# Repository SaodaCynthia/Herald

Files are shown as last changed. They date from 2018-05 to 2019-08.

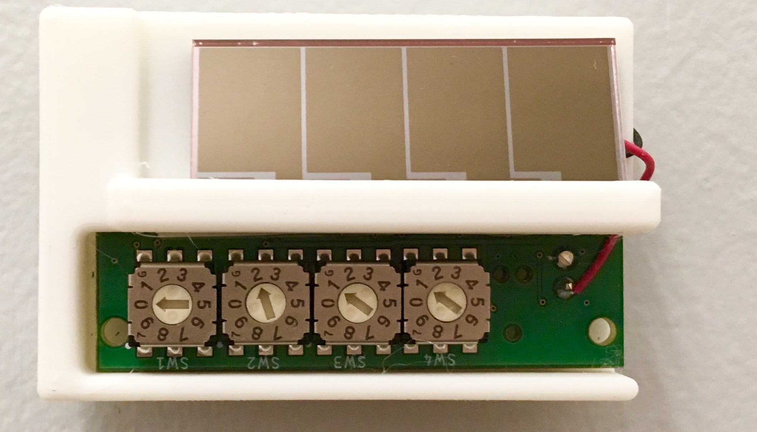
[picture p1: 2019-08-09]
media/herald.jpg

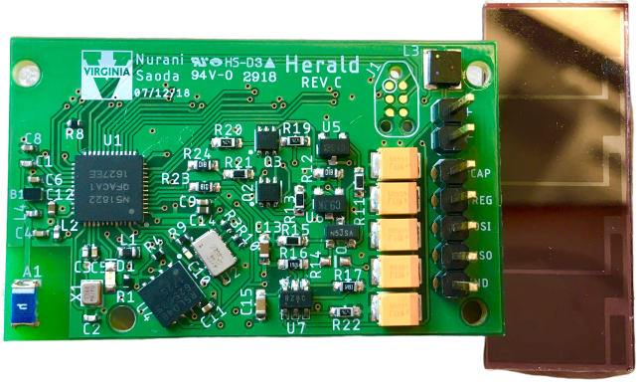
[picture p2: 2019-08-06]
media/prototype.png

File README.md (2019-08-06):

# Herald

Herald is a solar energy harvesting room number transmitter BLE beacon. It has been tested and deployed in 3 different indoor settings: a lab space with sunlight , indoor office with only indoor lights and an industrial steam plant with indoor lights. This project shows that solar energy harvesting beacons has promising future in indoor settings and performance can be further improved with planned deployment of beacons and a minimum indoor light intensity level.

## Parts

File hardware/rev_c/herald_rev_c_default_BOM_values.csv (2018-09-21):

Qty | Value | Device | Parts | Library | Description | DIGIKEY | MANUFACTURER | MOUSER | MPN | NEWARK | PROD_ID | RICHARDSON_RFPD | VALUE
5 | 100uF | 1210_CAP_POLARIZED | C16, C17, C18, C19, C20 | Gecko |  | ?478-3130-1-ND? |  |  | ?TCJB107M006R0070?
1 | BAL-NRF01D3 | BAL-NRF01D3 | B1 | chips | 50 ohm nominal input / conjugate match balun to nRF51422-QFAA, | 497-13637-1-ND | STMicroelectronics | 511-BAL-NRF01D3 | BAL-NRF01D3
1 | 10uF | CAP | C13 | Gecko |  | 445-6853-1-ND |  |  | C1608X5R1A106M080AC?
1 | 4.7uF | CAP | C15 | Gecko |  | 1276-2087-1-ND |  |  | CL10B475KQ8NQNC
2 | 0.1uF | CAPACITOR0402_CAP | C9, C11 | passives | SMD Capacitor | 399-7332-1-ND? |  |  | C0402C104M4VACTU?
1 | 1.5pF | CAPACITOR0402_CAP | C1 | passives | SMD Capacitor | 399-1002-1-ND? |  |  | ?C0402C159C5GACTU?
1 | 10nF | CAPACITOR0402_CAP | C10 | passives | SMD Capacitor | ?720-1362-1-ND |  |  | VJ0402Y103KXXAC?
2 | 12pF | CAPACITOR0402_CAP | C2, C3 | passives | SMD Capacitor | ?399-1013-1-ND? |  |  | C0402C120J5GACTU?
2 | 1nF | CAPACITOR0402_CAP | C4, C5 | passives | SMD Capacitor | ?311-1036-1-ND? |  |  | CC0402KRX7R9BB102?
1 | 1uF | CAPACITOR0402_CAP | C12 | passives | SMD Capacitor | 445-13185-1-ND |  |  | CGB2A1X5R1E105K033BC
1 | 2.2nF | CAPACITOR0402_CAP | C6 | passives | SMD Capacitor | ?490-5419-1-ND? |  |  | ?GRM155R71E222KA01D?
1 | 4.7uF | CAPACITOR0402_CAP | C14 | passives | SMD Capacitor | 445-5947-1-ND? |  |  | ?C1005X5R0J475K050BC?
1 | 47nF | CAPACITOR0402_CAP | C8 | passives | SMD Capacitor | ?445-1264-1-ND? |  |  | ?C1005X7R1C473K050BC?
1 |  | CONN_02 | J2 | SparkFun-Retired | Multi connection point. Often used as Generic Header-pin footprint for 0.1 inch spaced/style header connections | 732-5315-ND |  |  | 61300211121
1 | FM25LBTDFN-8 | FM25LBTDFN-8 | U4 | chips | IC FRAM 4KBIT 10MHZ 8SOIC | FM25L04B-DGRA-ND |  | 877-FM25L04B-DG | FM25L04B-DG?
1 | FRACTUS-2.4GHZ-FR05-S1-N-0-110 | FRACTUS-2.4GHZ-FR05-S1-N-0-110 | A1 | chips | Fractus Micro Reach Xtend |  |  |  | FR05-S1-N-0-110BULK |  |  | FR05-S1-N-0110B
1 | 15nH | INDUCTOR0402 | L2 | passives | A very specific inductor | 587-1521-1-ND |  |  | HK100515NJ-T?
1 | 6.8nH | INDUCTOR0402 | L4 | passives | A very specific inductor | 587-1515-1-ND |  |  | ?HK10056N8J-T?
1 | 10uH | INDUCTOR0603 | L1 | passives | A very specific inductor | 490-4025-1-ND |  |  | CK1608100M-T?
1 | 4.7uH | L-US | L3 | Gecko |  |  |  | 994-EPL3012-472MLB | EPL3012-472MLB
1 | BLUE | LED-BLUE0603 | D1 | SparkFun-LED | Blue SMD LED | 160-1837-1-ND |  |  | LTST-C194TBKT |  | DIO-08575 |  | BLUE
1 | MCP1640T | MCP1640 | U7 | Gecko |  | MCP1640T-I/CHYDKR-ND? |  |  | MCP1640T-I/CHY?
1 | MN1382S 2.0V | MN1382S | U5 | umich |  |  |  |  | TC54VC2102ECB713
1 | TC54VC 2.9V | MN1382S | U6 | umich |  | ?TC54VC2902ECB71DKR-ND? |  |  | TC54VC2902ECB713?
1 | NRF51822QF | NRF51822QF | U1 | chips | Multiprotocol Bluetooth® 4.0 low energy/2.4 GHz RF SoC | 1490-1042-1-ND | Nordic Semi | 949-NRF51822-QFAC-R7 | NRF51822-QFAC-R7
1 |  | PINHD-1X5 | JP1 | pinhead | PIN HEADER | 732-5318-ND |  |  | 61300511121
1 |  | PMOSSOT23 | Q1 | berkeley-epic | MOS FET |  |  |  | SI2305CDS-T1-GE3 | 55R1909
4 | 100K | RESISTOR | R11, R13, R15, R21 | Gecko |  | ?P100KHCT-ND? |  |  | ?ERJ-3EKF1003V?
1 | 100K (DNP) | RESISTOR | R14 | Gecko |  | ?P100KHCT-ND? |  |  | ?ERJ-3EKF1003V?
3 | 1K | RESISTOR | R12, R23, R24 | Gecko |  | ?A106049CT-ND? |  |  | ?CRG0603F1K0?
3 | 470K | RESISTOR | R19, R20, R22 | Gecko |  | ?1276-4902-1-ND? |  |  | ?RC1608F474CS?
1 | 649K | RESISTOR | R17 | Gecko |  | 541-649KHCT-ND? |  |  | ?CRCW0603649KFKEA?
1 | 976K | RESISTOR | R16 | Gecko |  | 541-976KHCT-ND |  |  | CRCW0603976KFKEA
2 | 10k | RESISTOR0402_RES | R3, R9 | passives | Resistor | RHM10KCECT-ND |  |  | ?ERJ-2GEJ103X?
1 | 12k | RESISTOR0402_RES | R8 | passives | Resistor | RHM12.0KCDCT-ND |  |  | ?RC0402FR-0712KL?
2 | 4.7k | RESISTOR0402_RES | R4, R10 | passives | Resistor | RHM4.7KCECT-ND |  |  | ?ERJ-2GEJ472X?
1 | 470 | RESISTOR0402_RES | R1 | passives | Resistor | RHM470CECT-ND |  |  | ERA-2AED471X
1 | RV-3049-C3 | RV-3049-C3 | U2 | chips | The RV-3049-C3 is an ultra miniature Real-Time-Clock Module |  |  |  | RV-3049-C3-32.768kHz-OPTION-A-TA-QC | RV-3049-C3
4 | SH7010TA | SH7010TA | SW1, SW2, SW3, SW4 | sh7010TA |  | 563-1207-2-ND |  |  | ?SH-7010TA?
1 | TC2030-JLINK-NL | TC2030-JLINK-NL | J1 | connector |  |  |  |  | TC2030-MCP-NL
1 | 16MHz | TXC-8Y | X1 | crystals | 2mmx1.6mm SMD Crystal | 887-2003-1-ND |  |  | ?8Y-16.000MAAV-T?
2 | US6M11TR | US6M11TR | Q2, Q3 | DUALMOS |  | US6M11CT-ND |  |  | ?US6M11TR?
1 |  | Solar Cell |  |  |  | 869-1000-ND |  |  | AM-1417CA

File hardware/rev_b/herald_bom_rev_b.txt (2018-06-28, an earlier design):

Partlist exported from C:/Users/ns8nf/Documents/eagle/sensorfinal/sensor/sensor/herald_rev_b.sch at 6/7/2018 6:50 PM

Part Value                          Device                         Package                         Description                                                    DIGIKEY          MANUFACTURER       MOUSER               MPN               NEWARK     PROD_ID   RICHARDSON_RFPD VALUE
A1   FRACTUS-2.4GHZ-FR05-S1-N-0-110 FRACTUS-2.4GHZ-FR05-S1-N-0-110 FRACTUS-ANTENNA-FR05-S1-N-0-110 Fractus Micro Reach Xtend                                                                                                                                      FR05-S1-N-0110B      
B1   BAL-NRF01D3                    BAL-NRF01D3                    BAL-NRF01D3                     50 ohm nominal input / conjugate match balun to nRF51422-QFAA, 497-13637-1-ND   STMicroelectronics 511-BAL-NRF01D3      BAL-NRF01D3                                                 
C1   1.5pF                          CAPACITOR0402_CAP              0402_CAP                        SMD Capacitor                                                                                                                                                                       
C2   12pF                           CAPACITOR0402_CAP              0402_CAP                        SMD Capacitor                                                                                                                                                                       
C3   12pF                           CAPACITOR0402_CAP              0402_CAP                        SMD Capacitor                                                                                                                                                                       
C4   1nF                            CAPACITOR0402_CAP              0402_CAP                        SMD Capacitor                                                                                                                                                                       
C5   1nF                            CAPACITOR0402_CAP              0402_CAP                        SMD Capacitor                                                                                                                                                                       
C6   2.2nF                          CAPACITOR0402_CAP              0402_CAP                        SMD Capacitor                                                                                                                                                                       
C8   47nF                           CAPACITOR0402_CAP              0402_CAP                        SMD Capacitor                                                                                                                                                                       
C9   0.1uF                          CAPACITOR0402_CAP              0402_CAP                        SMD Capacitor                                                                                                                                                                       
C10  10nF                           CAPACITOR0402_CAP              0402_CAP                        SMD Capacitor                                                                                                                                                                       
C11  0.1uF                          CAPACITOR0402_CAP              0402_CAP                        SMD Capacitor                                                                                                                                                                       
C12  1uF                            CAPACITOR0402_CAP              0402_CAP                        SMD Capacitor                                                                                                                                                                       
C13  10uF                           CAP                            R0603B                                                                                                                                                                                                              
C14  4.7uF                          CAPACITOR0402_CAP              0402_CAP                        SMD Capacitor                                                                                                                                                                       
C15  4.7uF                          CAP                            R0603B                                                                                                                                                                                                              
C16  100uF                          1210_CAP_POLARIZED             CAP1210                                                                                                                                                                                                             
C17  100uF                          1210_CAP_POLARIZED             CAP1210                                                                                                                                                                                                             
C18  100uF                          1210_CAP_POLARIZED             CAP1210                                                                                                                                                                                                             
C19  100uF                          1210_CAP_POLARIZED             CAP1210                                                                                                                                                                                                             
C20  100uF                          1210_CAP_POLARIZED             CAP1210                                                                                                                                                                                                             
D1   BLUE                           LED-BLUE0603                   LED-0603                        Blue SMD LED                                                                                                                                         DIO-08575                 BLUE 
J1   TC2030-JLINK-NL                TC2030-JLINK-NL                TC2030-IDC-NL                                                                                                                                                                                                       
JP1                                 PINHD-1X6                      1X06                            PIN HEADER                                                                                                                                                                          
JP2                                 PINHD-1X2                      1X02                            PIN HEADER                                                                                                                                                                          
L1   10uH                           INDUCTOR0603                   0603_CAP                        A very specific inductor                                       490-4025-1-ND                                                                                                        
L2   15nH                           INDUCTOR0402                   0402_CAP                        A very specific inductor                                       587-1521-1-ND                                                                                                        
L3   4.7uH                          L-US                           L2828                                                                                                                                                                                                               
L4   6.8nH                          INDUCTOR0402                   0402_CAP                        A very specific inductor                                       587-1521-1-ND                                                                                                        
Q1                                  PMOSSOT23                      SOT-23                          MOS FET                                                                                                                                                                             
Q2   US6M11TR                       US6M11TR                       TUMT6                                                                                          US6M11CT-ND                                                                                                          
Q3   US6M11TR                       US6M11TR                       TUMT6                                                                                          US6M11CT-ND                                                                                                          
R1   470                            RESISTOR0402_RES               0402_RES                        Resistor                                                       RHM470CECT-ND                                                                                                        
R3   10k                            RESISTOR0402_RES               0402_RES                        Resistor                                                       RHM10KCECT-ND                                                                                                        
R4   4.7k                           RESISTOR0402_RES               0402_RES                        Resistor                                                       RHM4.7KCECT-ND                                                                                                       
R8   12k                            RESISTOR0402_RES               0402_RES                        Resistor                                                       RHM12.0KCDCT-ND                                                                                                      
R9   10k                            RESISTOR0402_RES               0402_RES                        Resistor                                                       RHM10KCECT-ND                                                                                                        
R10  4.7k                           RESISTOR0402_RES               0402_RES                        Resistor                                                       RHM4.7KCECT-ND                                                                                                       
R11  100K                           RESISTOR                       R0603B                                                                                                                                                                                                              
R12  1K                             RESISTOR                       R0603B                                                                                                                                                                                                              
R13  100K                           RESISTOR                       R0603B                                                                                                                                                                                                              
R14  100K (DNP)                     RESISTOR                       R0603B                                                                                                                                                                                                              
R15  100K                           RESISTOR                       R0603B                                                                                                                                                                                                              
R16  976K                           RESISTOR                       R0603B                                                                                                                                                                                                              
R17  649K                           RESISTOR                       R0603B                                                                                                                                                                                                              
R19  470K                           RESISTOR                       R0603B                                                                                                                                                                                                              
R20  470K                           RESISTOR                       R0603B                                                                                                                                                                                                              
R21  100K                           RESISTOR                       R0603B                                                                                                                                                                                                              
R22  470K                           RESISTOR                       R0603B                                                                                                                                                                                                              
R23  1K                             RESISTOR                       R0603B                                                                                                                                                                                                              
R24  1K                             RESISTOR                       R0603B                                                                                                                                                                                                              
SW1  SH7010TA                       SH7010TA                       SWTICH-6                                                                                       563-1207-2-ND                                                                                                        
SW2  SH7010TA                       SH7010TA                       SWTICH-6                                                                                       563-1207-2-ND                                                                                                        
SW3  SH7010TA                       SH7010TA                       SWTICH-6                                                                                       563-1207-2-ND                                                                                                        
SW4  SH7010TA                       SH7010TA                       SWTICH-6                                                                                       563-1207-2-ND                                                                                                        
U1   NRF51822QF                     NRF51822QF                     QFN-48-6MM                      Multiprotocol Bluetooth® 4.0 low energy/2.4 GHz RF SoC         1490-1042-1-ND   Nordic Semi        949-NRF51822-QFAC-R7 NRF51822-QFAC-R7                                            
U2   RV-3049-C3                     RV-3049-C3                     MICRO-CRYSTAL-C3                The RV-3049-C3 is an ultra miniature Real-Time-Clock Module                                                                               RV-3049-C3                                
U4   FM25LBTDFN-8                   FM25LBTDFN-8                   TDFN-8@1                        IC FRAM 4KBIT 10MHZ 8SOIC                                      FM25L04B-DGRA-ND                     877-FM25L04B-DG                                                                 
U5   MN1382S 2.0V                   MN1382S                        MINI-3DC                                                                                                                                                                                                            
U6   TC54VC 2.9V                    MN1382S                        MINI-3DC                                                                                                                                                                                                            
U7   MCP1640T                       MCP1640                        SOT-23-6                                                                                                                                                                                                            
X1   16MHz                          TXC-8Y                         TXC-8Y                          2mmx1.6mm SMD Crystal                                          887-2003-1-ND

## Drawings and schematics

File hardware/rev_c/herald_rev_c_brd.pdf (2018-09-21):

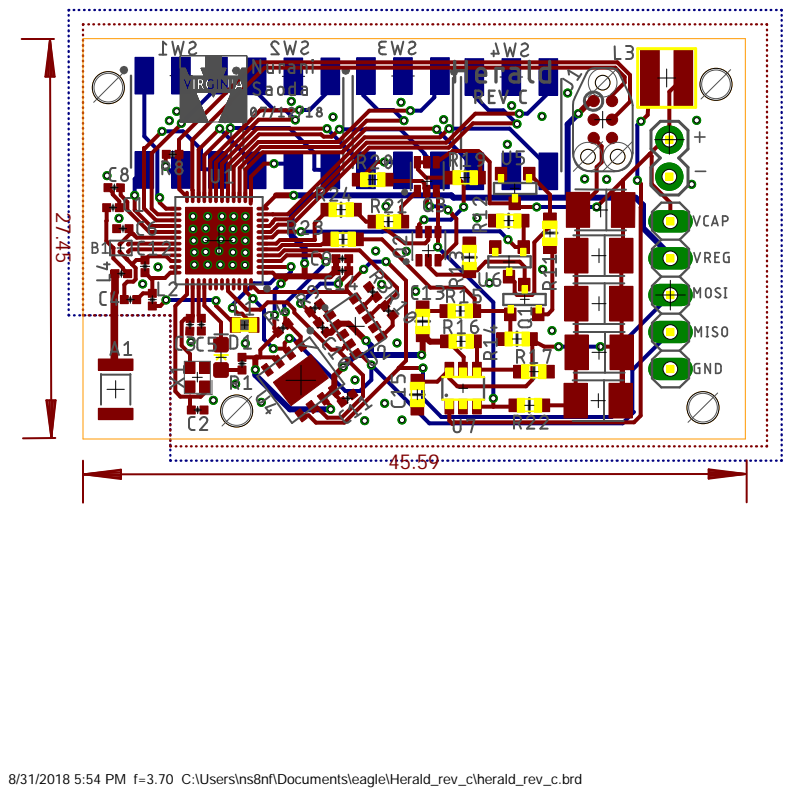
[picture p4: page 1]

8/31/2018 5:54 PM f=3.70 C:\Users\ns8nf\Documents\eagle\Herald_rev_c\herald_rev_c.brd

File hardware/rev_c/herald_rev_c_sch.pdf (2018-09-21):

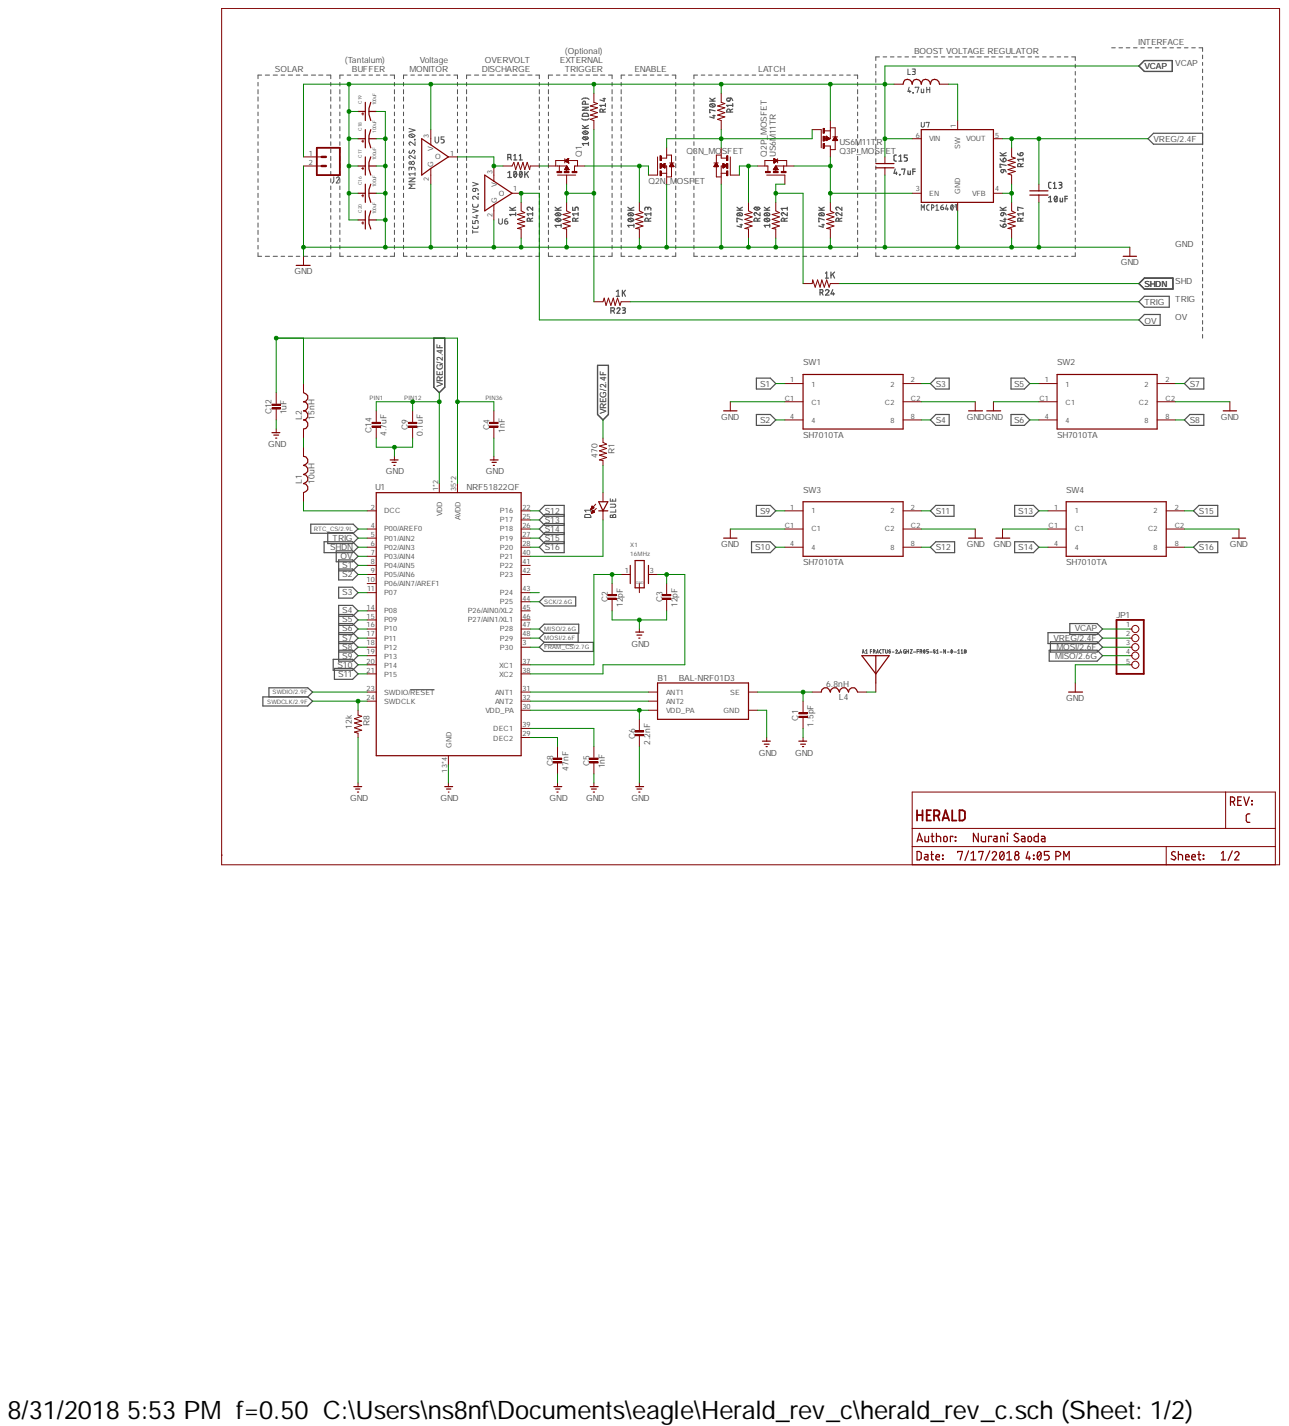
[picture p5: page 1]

8/31/2018 5:53 PM f=0.50 C:\Users\ns8nf\Documents\eagle\Herald_rev_c\herald_rev_c.sch (Sheet: 1/2)

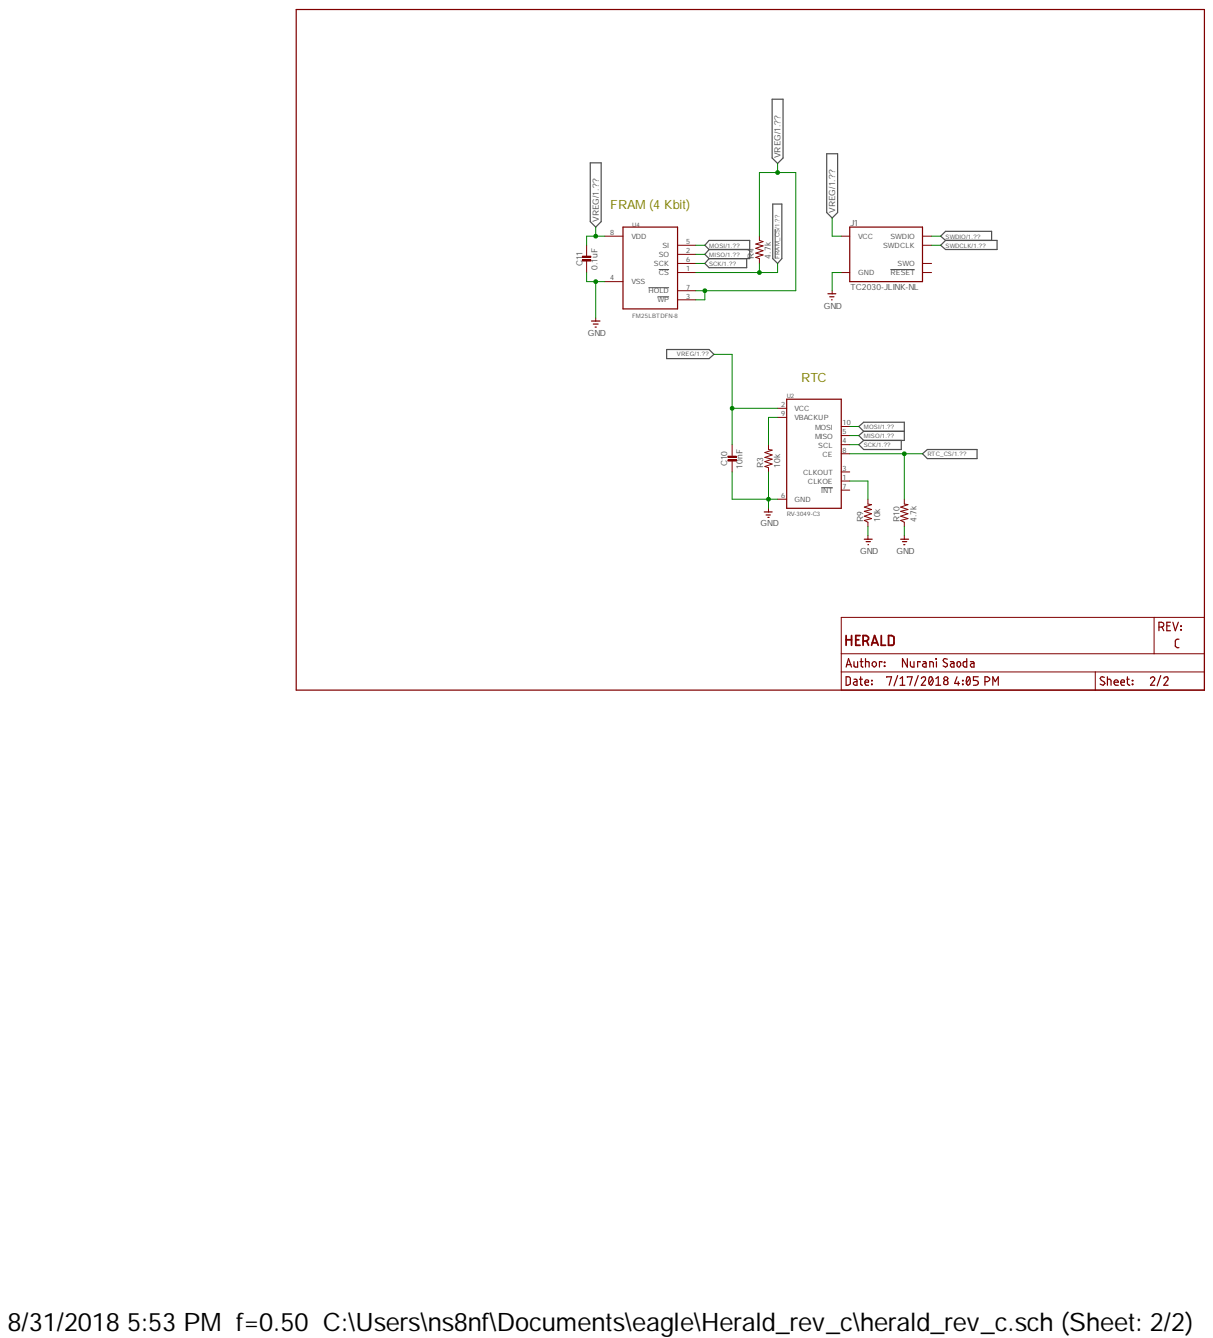
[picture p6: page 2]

8/31/2018 5:53 PM f=0.50 C:\Users\ns8nf\Documents\eagle\Herald_rev_c\herald_rev_c.sch (Sheet: 2/2)

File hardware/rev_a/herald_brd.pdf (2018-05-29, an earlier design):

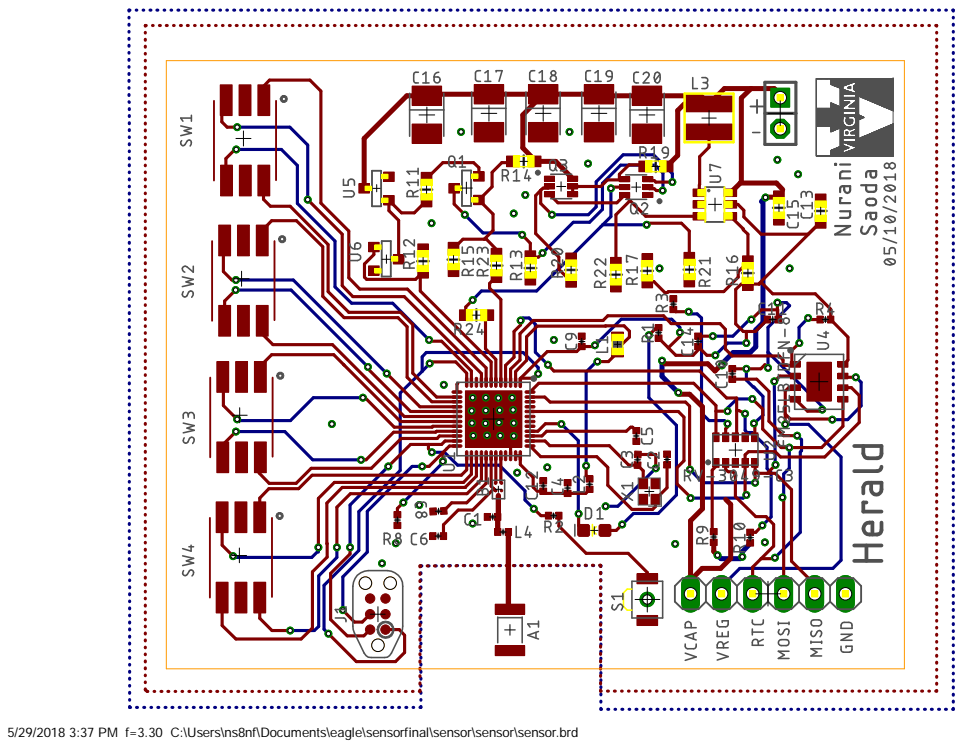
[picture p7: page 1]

5/29/2018 3:37 PM f=3.30 C:\Users\ns8nf\Documents\eagle\sensorfinal\sensor\sensor\sensor.brd

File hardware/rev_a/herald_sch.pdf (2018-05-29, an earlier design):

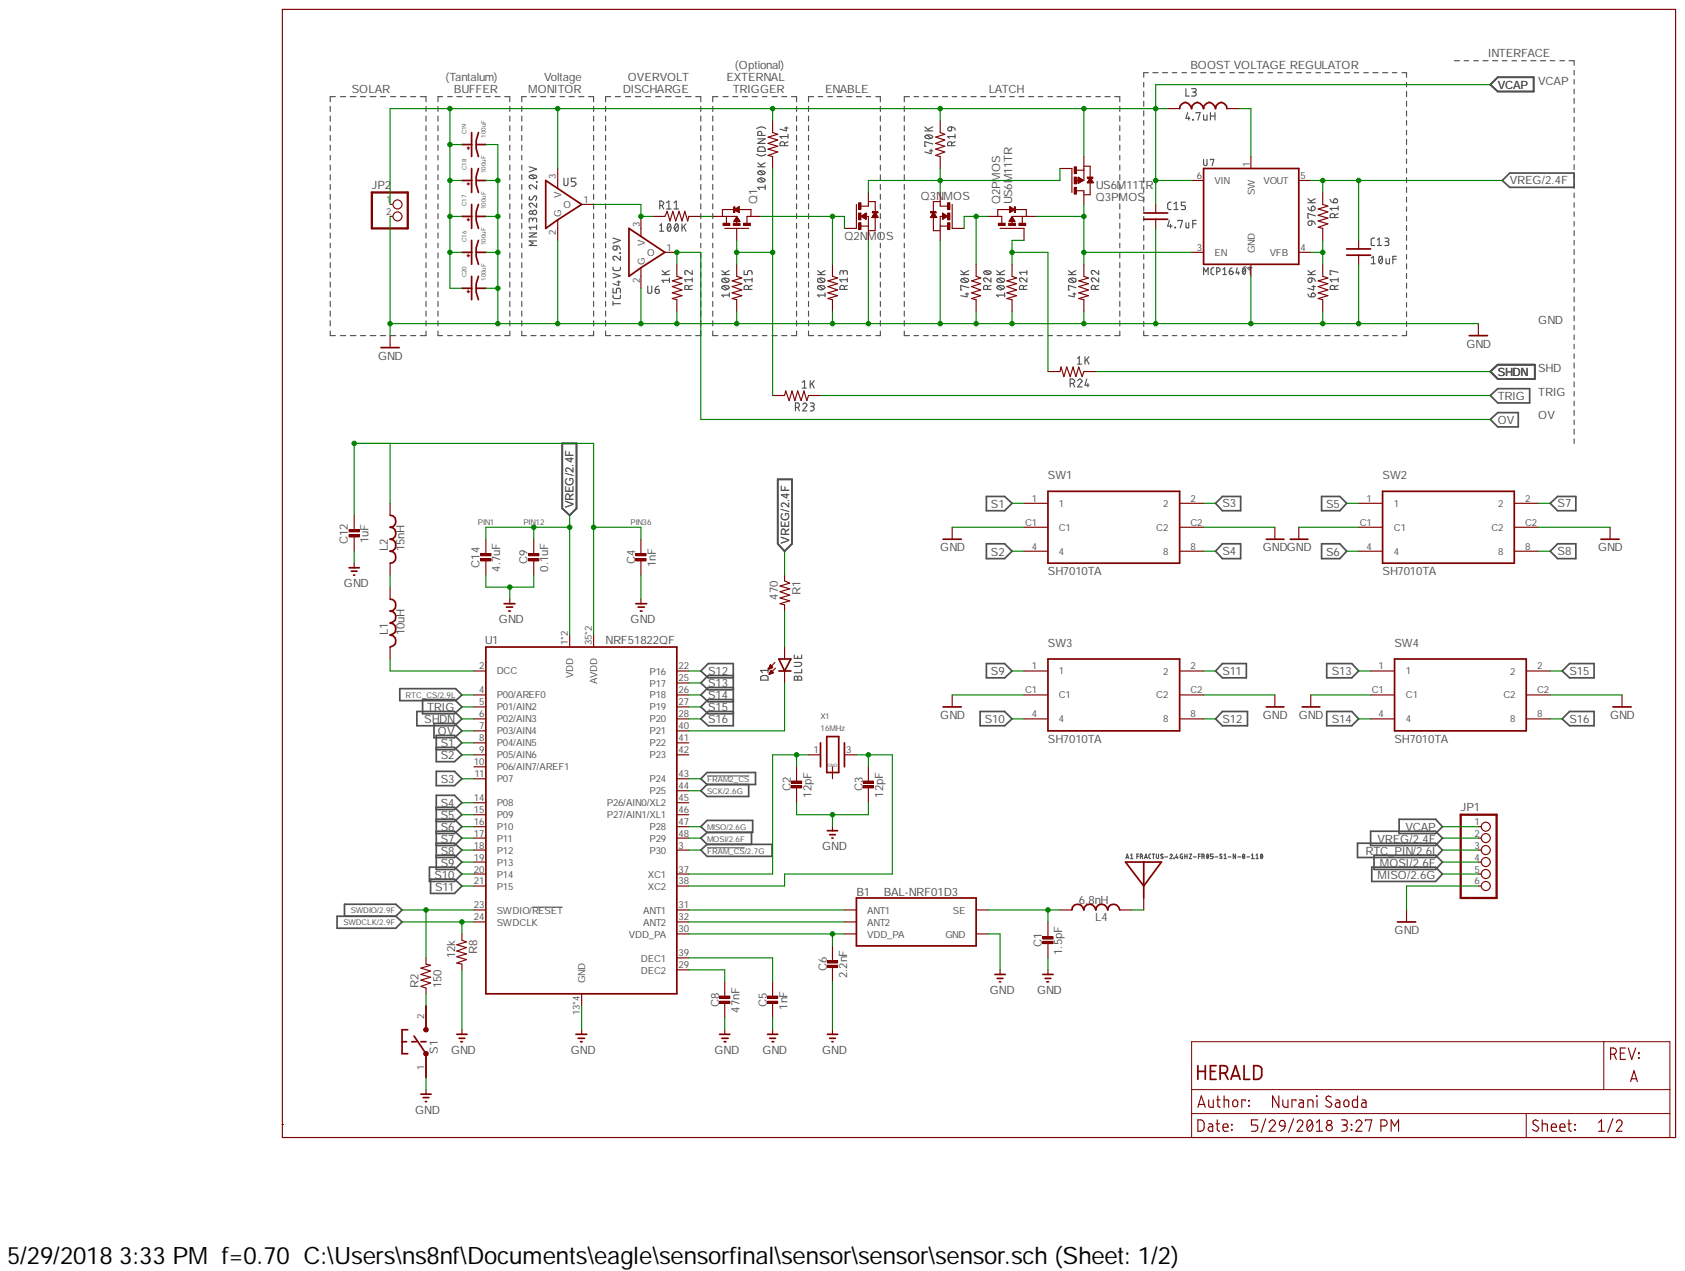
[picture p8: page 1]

5/29/2018 3:33 PM f=0.70 C:\Users\ns8nf\Documents\eagle\sensorfinal\sensor\sensor\sensor.sch (Sheet: 1/2)

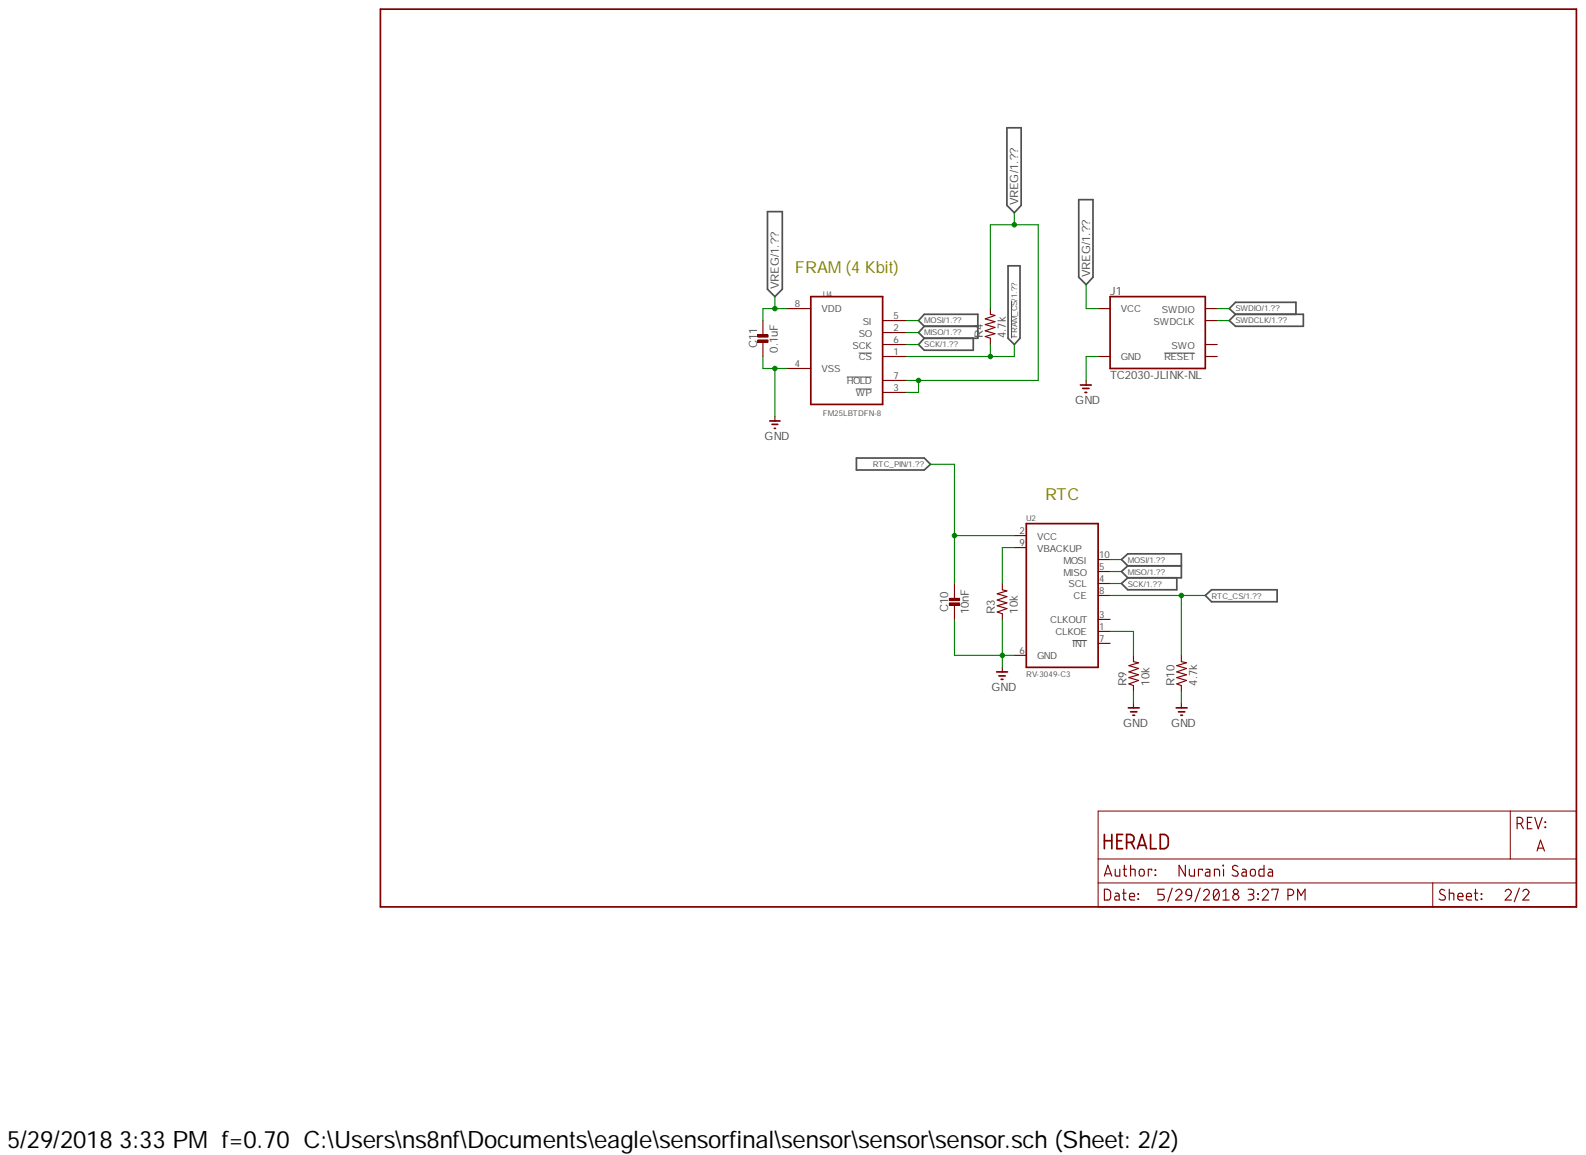
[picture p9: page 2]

5/29/2018 3:33 PM f=0.70 C:\Users\ns8nf\Documents\eagle\sensorfinal\sensor\sensor\sensor.sch (Sheet: 2/2)

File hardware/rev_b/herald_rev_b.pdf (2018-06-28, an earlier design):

6 EN

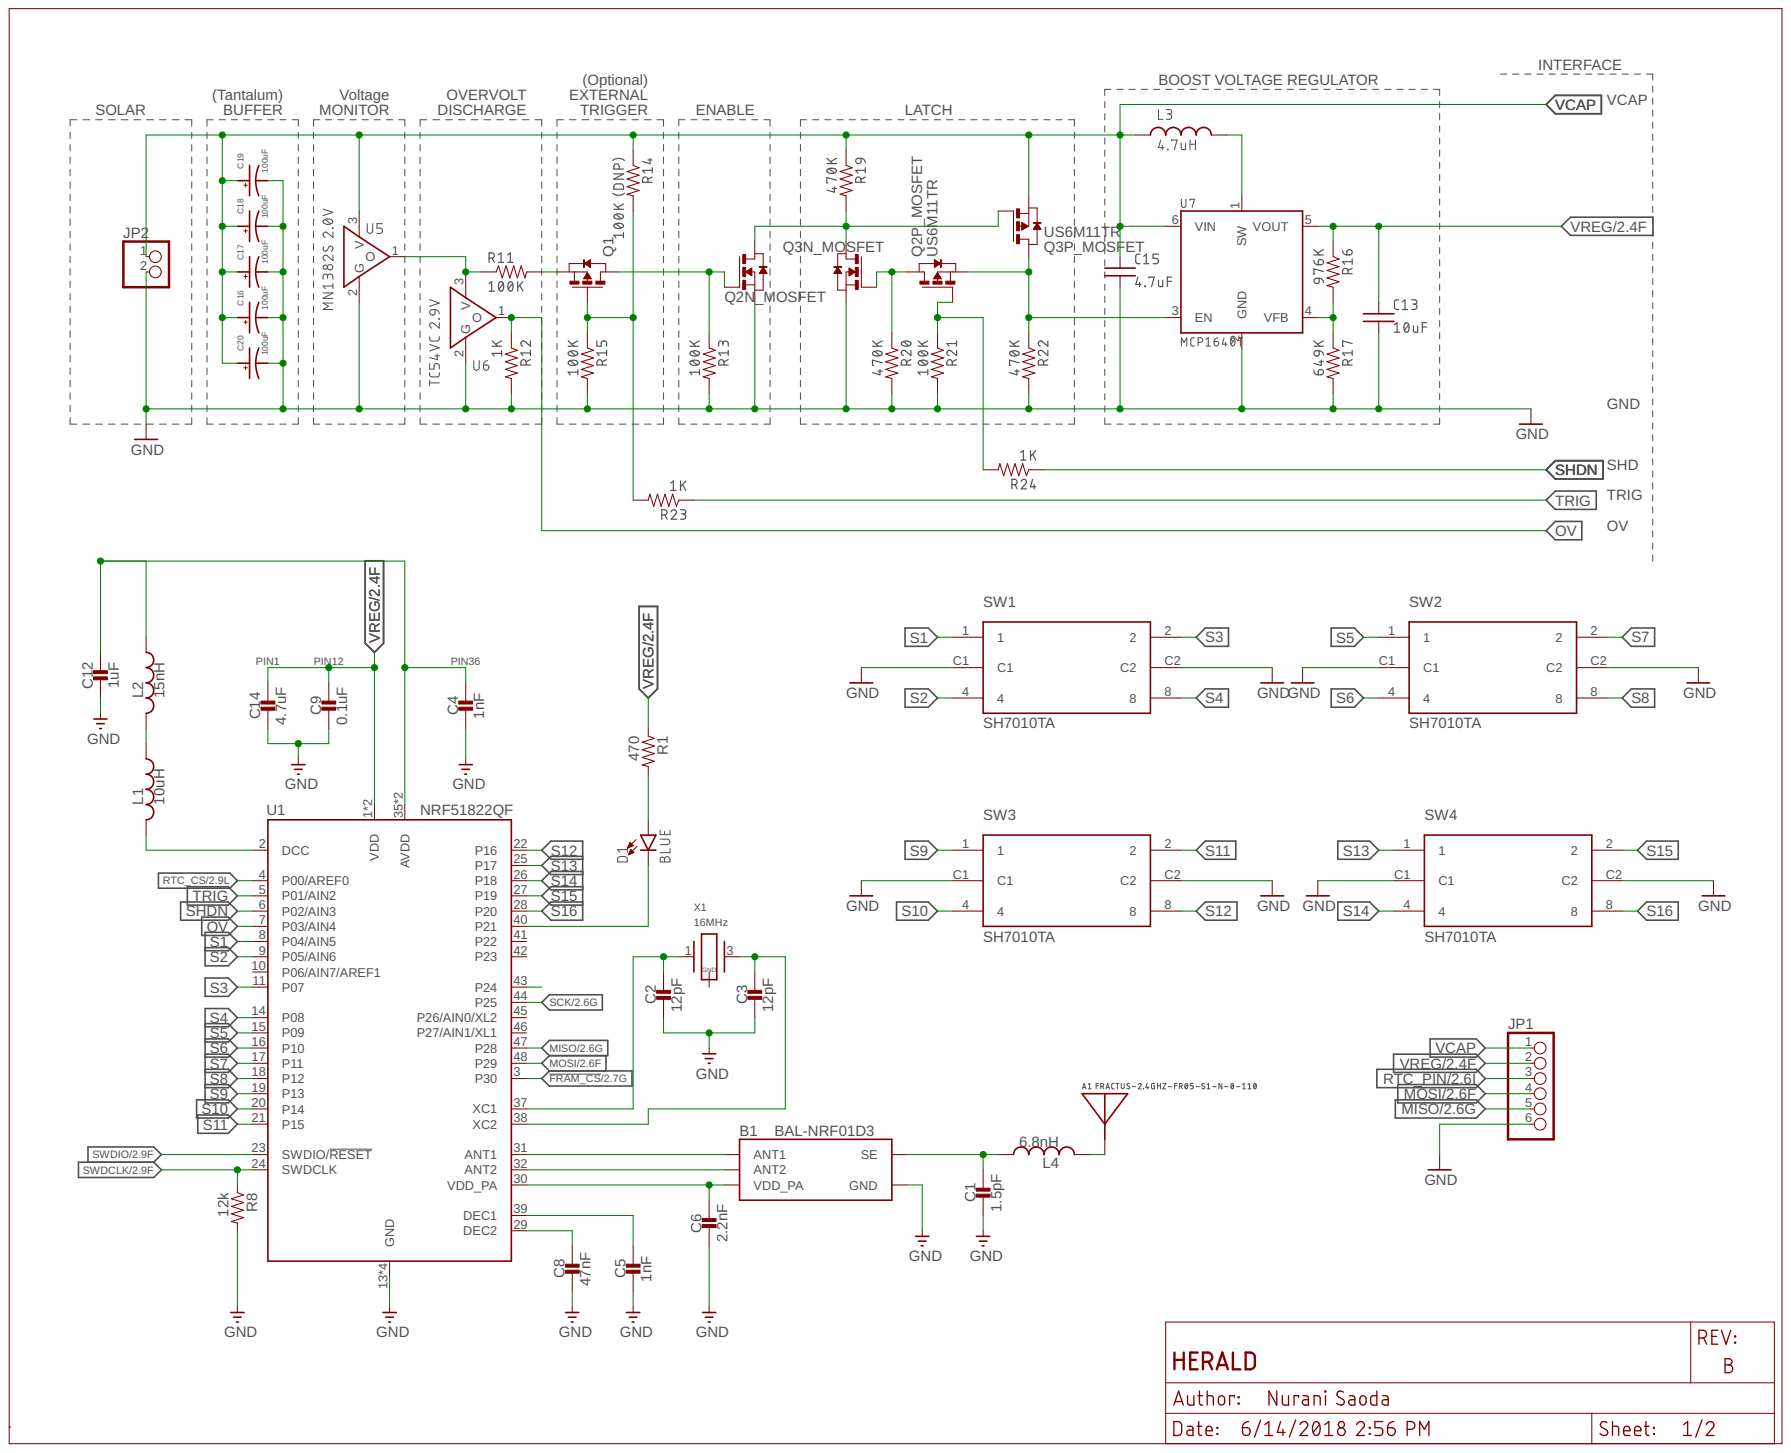
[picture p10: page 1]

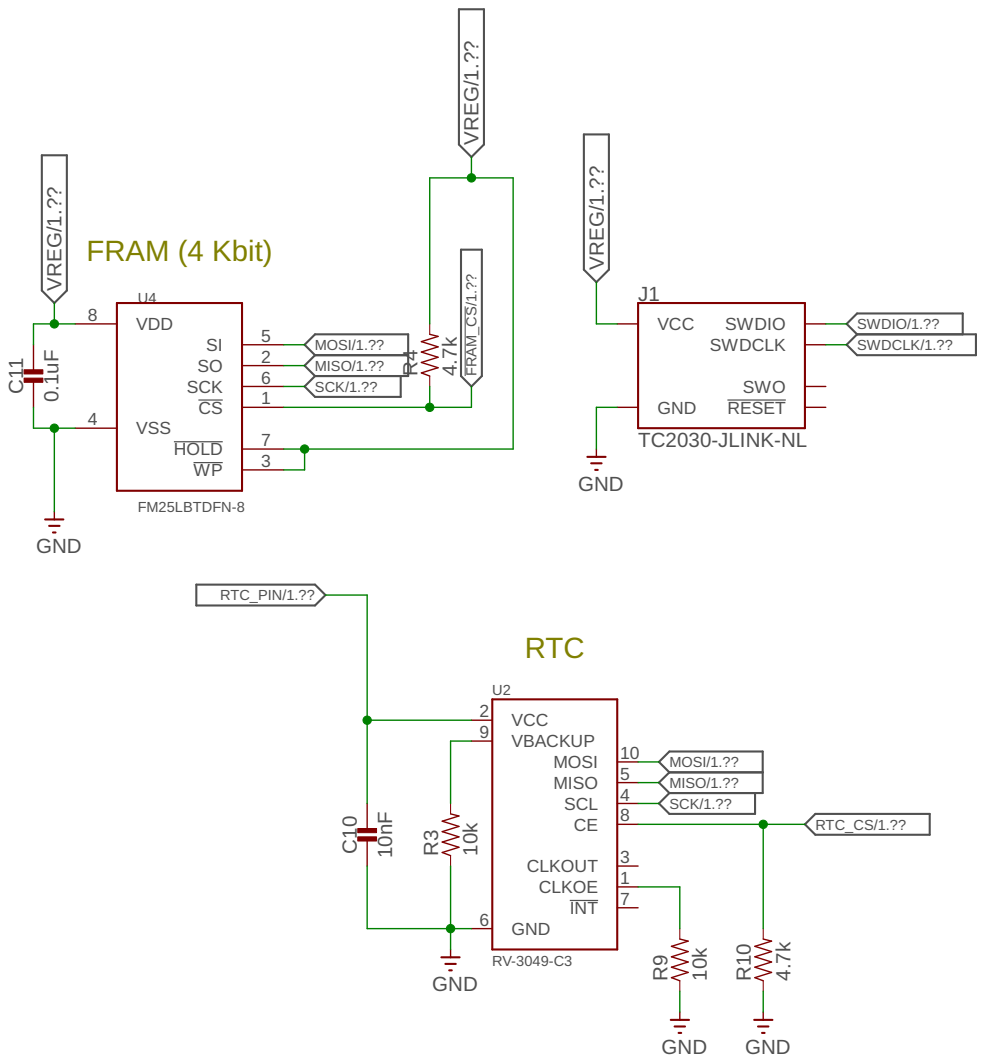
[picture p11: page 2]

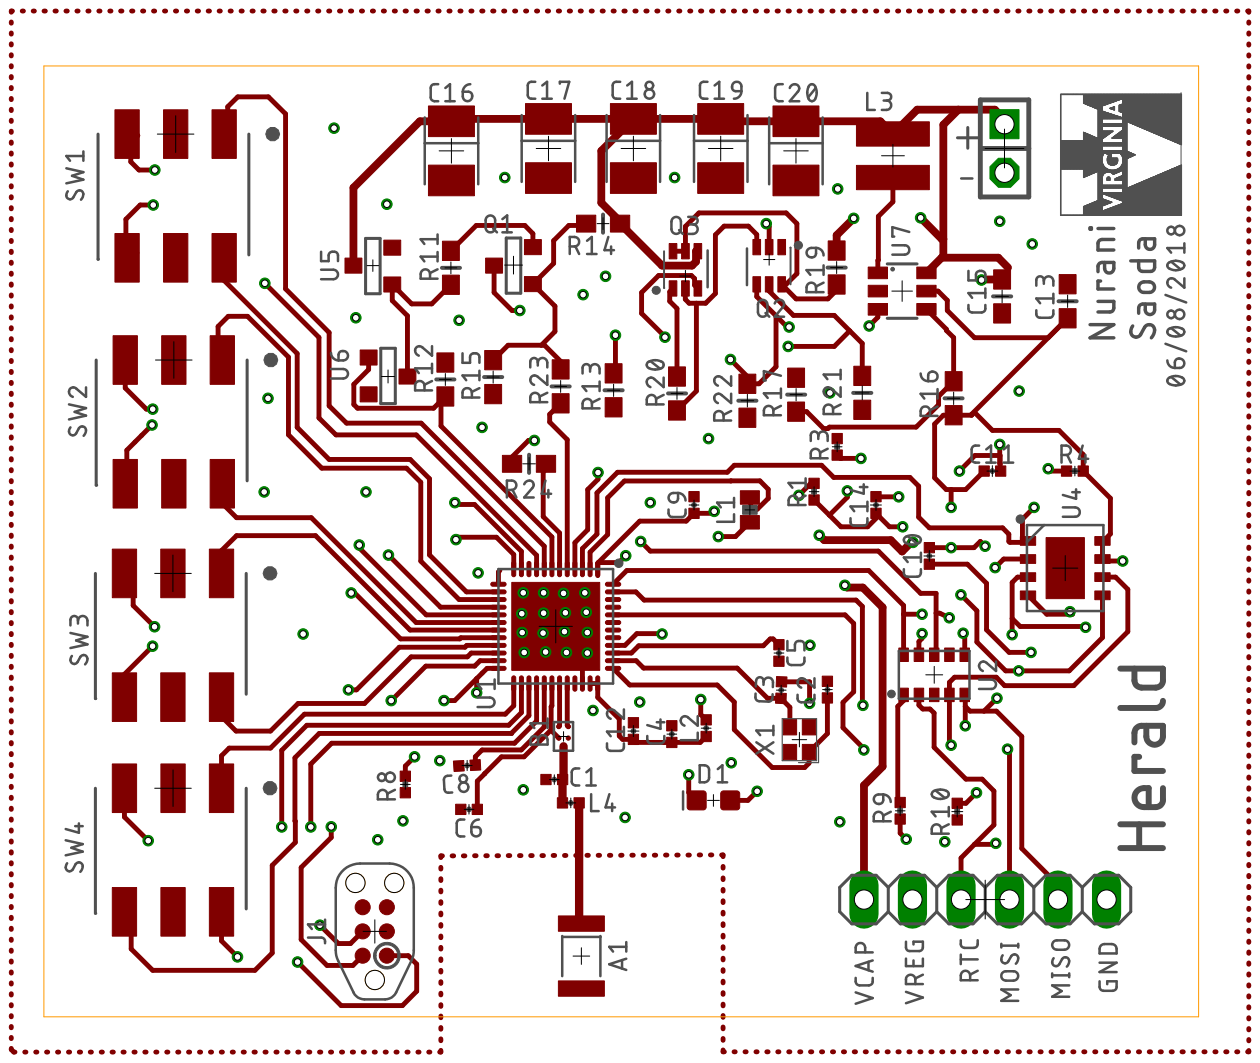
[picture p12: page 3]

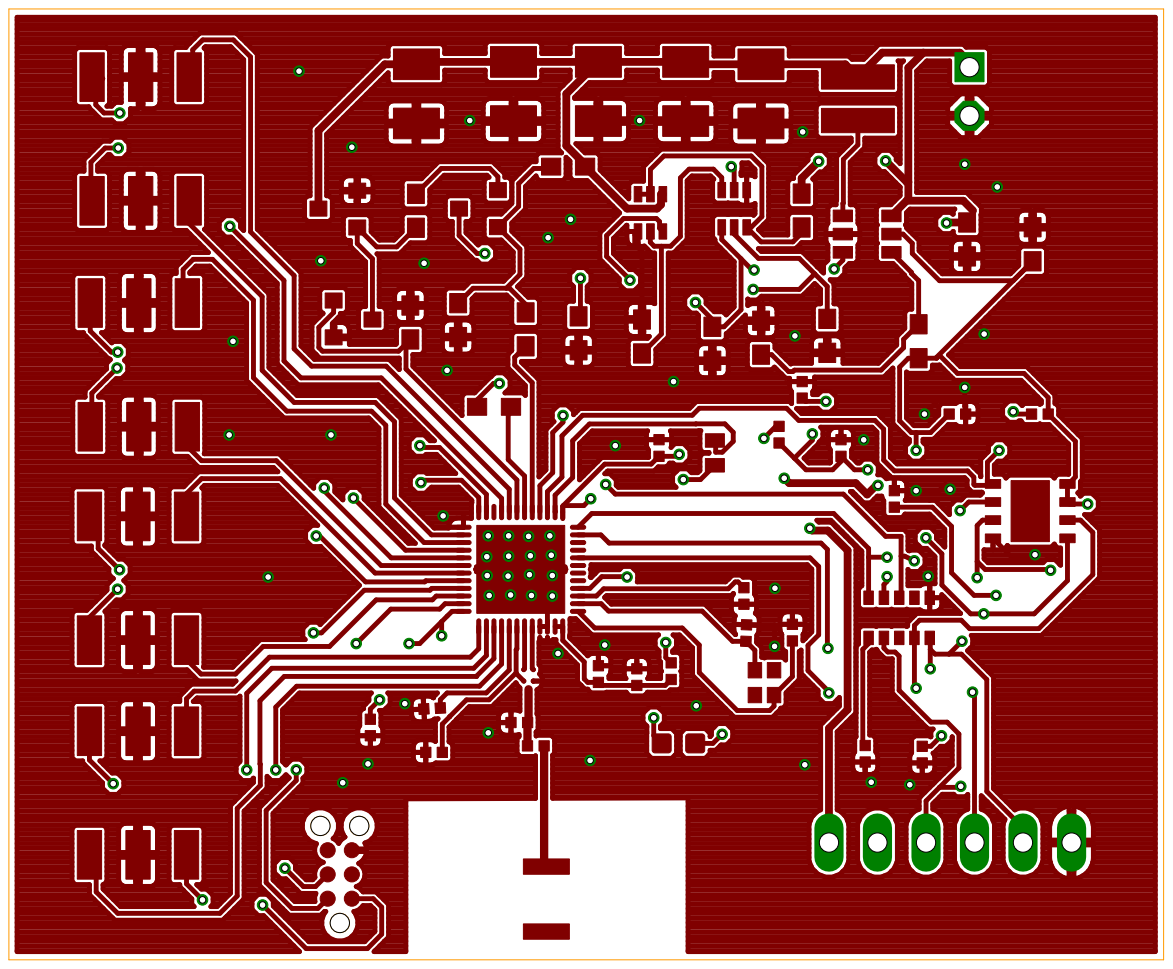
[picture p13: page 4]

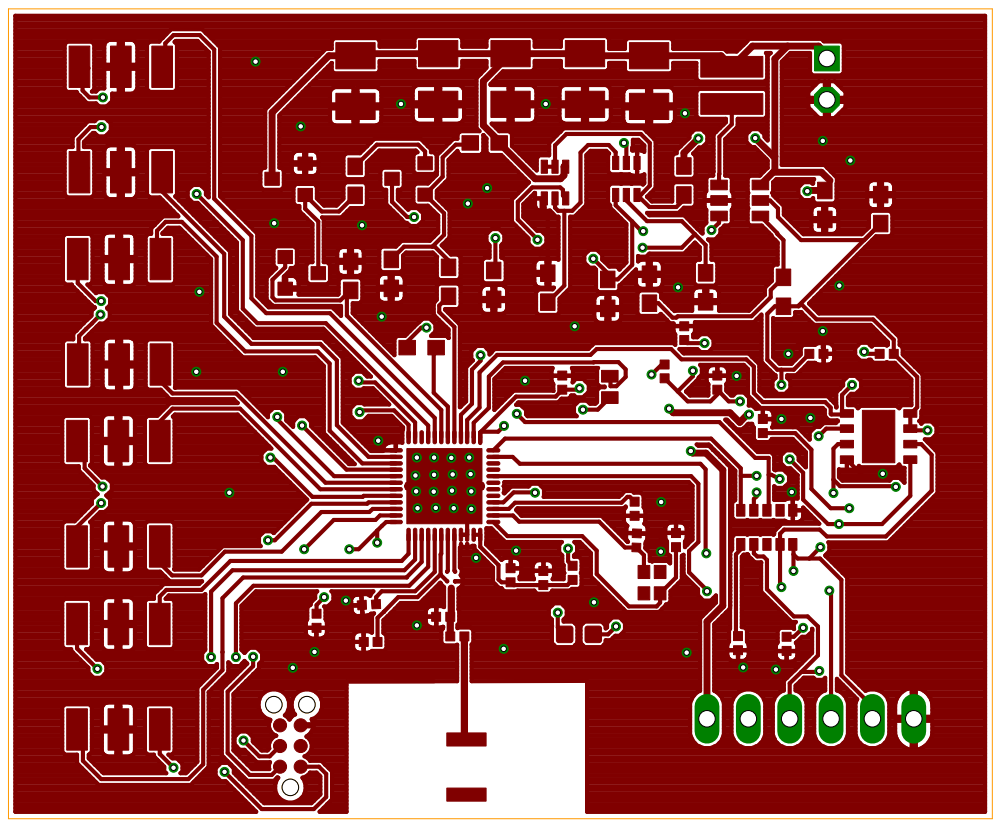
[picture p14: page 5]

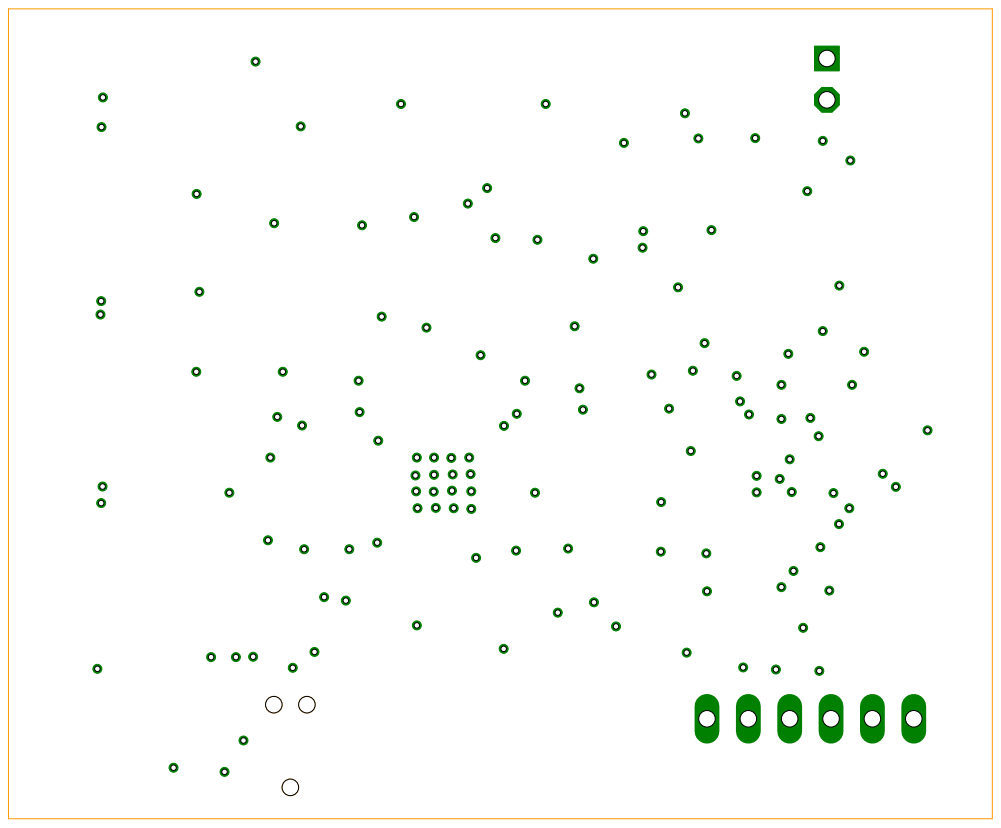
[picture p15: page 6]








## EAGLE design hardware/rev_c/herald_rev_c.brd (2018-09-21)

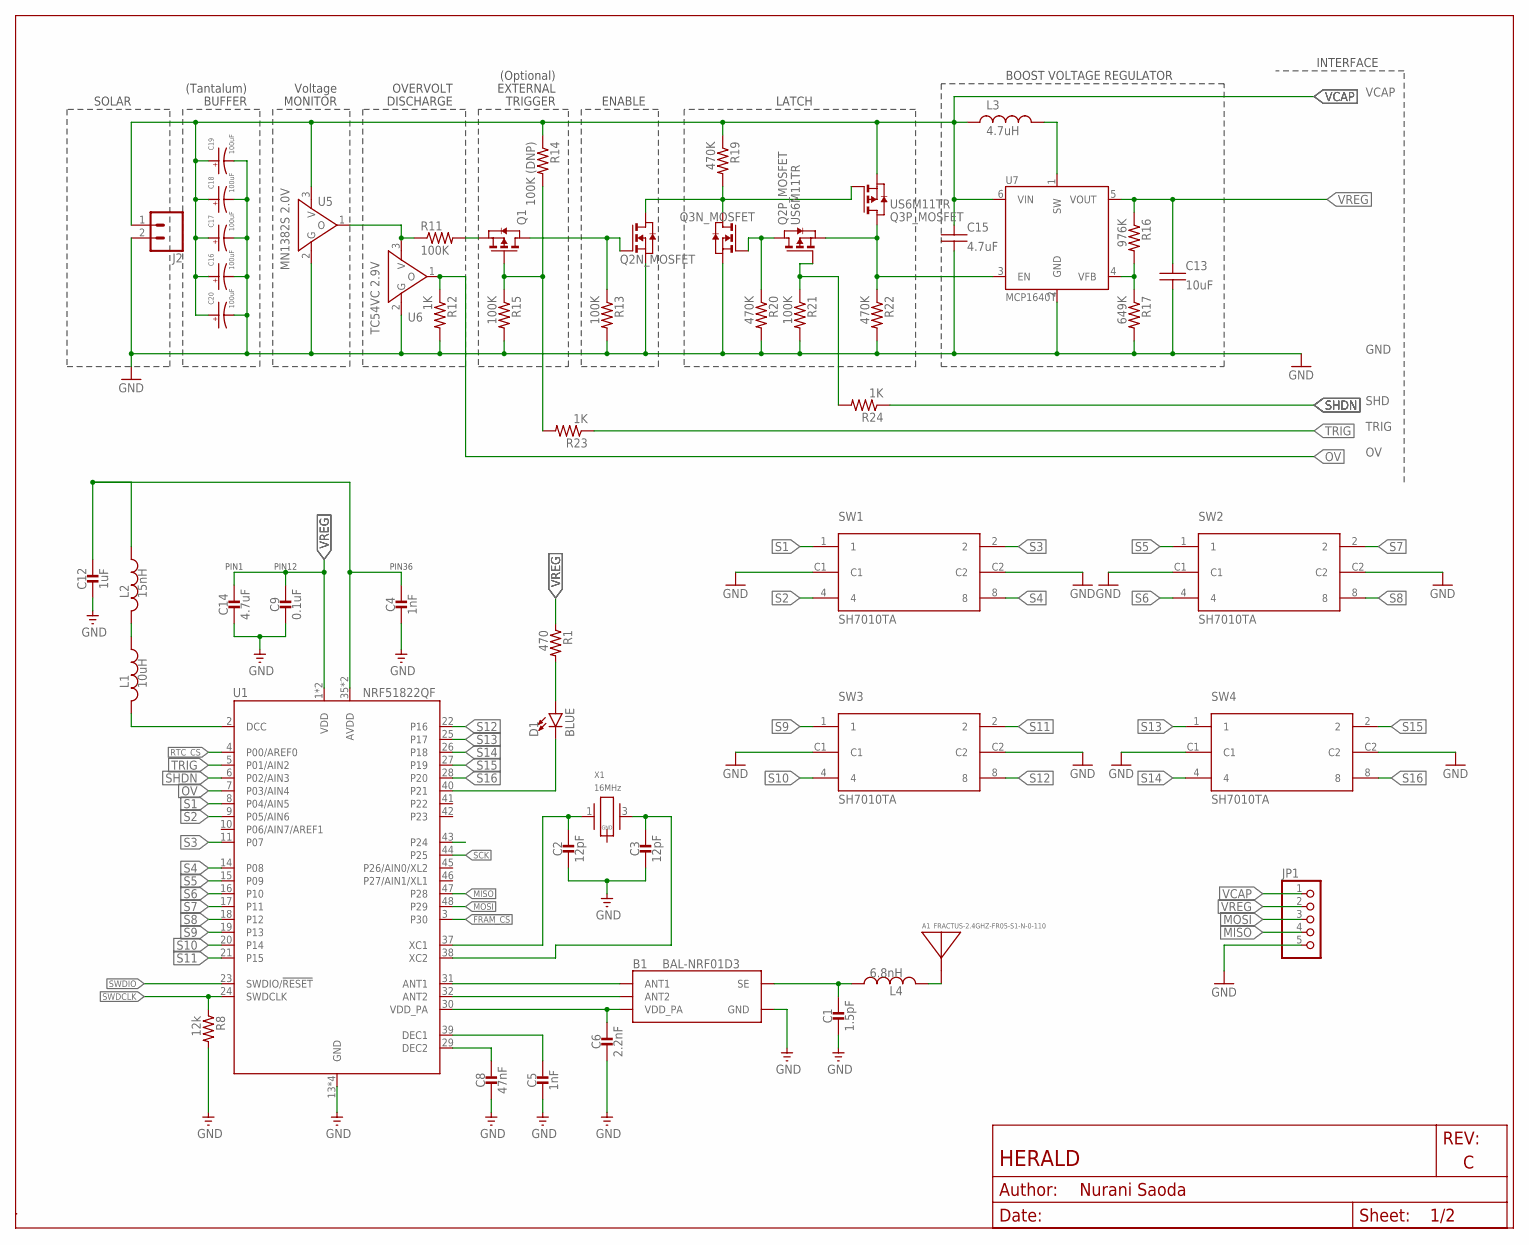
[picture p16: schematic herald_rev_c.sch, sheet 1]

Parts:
A1: FRACTUS-2.4GHZ-FR05-S1-N-0-110; FRACTUS-ANTENNA-FR05-S1-N-0-110
B1: BAL-NRF01D3
C1: 1.5pF; 0402_CAP
C2, C3: 12pF; 0402_CAP
C4, C5: 1nF; 0402_CAP
C6: 2.2nF; 0402_CAP
C8: 47nF; 0402_CAP
C9: 0.1uF; 0402_CAP
C12: 1uF; 0402_CAP
C13: 10uF; R0603B
C14: 4.7uF; 0402_CAP
C15: 4.7uF; R0603B
C16, C17, C18, C19, C20: 100uF; CAP1210
D1: BLUE; LED-0603
J2: CONN_02; 1X02
JP1: PINHD-1X5; 1X05
L1: 10uH; 0603_CAP; DIGIKEY 490-4025-1-ND
L2: 15nH; 0402_CAP; DIGIKEY 587-1521-1-ND
L3: 4.7uH; L2828
L4: 6.8nH; 0402_CAP; DIGIKEY 587-1521-1-ND
Q1: PMOSSOT23; SOT-23
Q2, Q3: US6M11TR; TUMT6
R1: 470; 0402_RES; DIGIKEY RHM470CECT-ND
R8: 12k; 0402_RES; DIGIKEY RHM12.0KCDCT-ND
R11, R13, R15, R21: 100K; R0603B
R12, R23, R24: 1K; R0603B
R14: 100K (DNP); R0603B
R16: 976K; R0603B
R17: 649K; R0603B
R19, R20, R22: 470K; R0603B
SW1, SW2, SW3, SW4: SH7010TA; SWTICH-6
U1: NRF51822QF; QFN-48-6MM; DIGIKEY 1490-1042-1-ND
U5: MN1382S 2.0V; MINI-3DC
U6: TC54VC 2.9V; MINI-3DC
U7: MCP1640T; SOT-23-6
X1: 16MHz; TXC-8Y; DIGIKEY 887-2003-1-ND

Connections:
!FRAM2_CS: U1.43 (P24)
!FRAM_CS: U1.3 (P30); also elsewhere on the board
GND: B1.GND, C1.2, C2.2, C3.2, C4.2, C5.2, C6.2, C8.2, C9.2, C12.2, C13.2, C14.2, C15.2, C16.ANODE, C17.ANODE, C18.ANODE, C19.ANODE, C20.ANODE, J2.2, JP1.5, Q2.1 (S), Q3.1 (S), R8.2, R12.2, R13.2, R15.2, R17.2, R20.2, R21.2, R22.2, SW1.C1, SW1.C2, SW2.C1, SW2.C2, SW3.C1, SW3.C2, SW4.C1, SW4.C2, U1.13 (GND), U1.33 (GND), U1.34 (GND), U1.GND, U5.2 (G), U6.2 (G), U7.2 (GND); also elsewhere on the board
MISO: JP1.4, U1.47 (P28); also elsewhere on the board
MOSI: JP1.3, U1.48 (P29); also elsewhere on the board
unnamed: A1.ANT, L4.2
unnamed: Q2.6 (D), Q3.5 (G), Q3.6 (D), R19.2
unnamed: B1.ANT1, U1.31 (ANT1)
unnamed: B1.ANT2, U1.32 (ANT2)
unnamed: D1.C, U1.40 (P21)
unnamed: D1.A, R1.2
unnamed: Q2.4 (S), Q3.3 (D), R22.1, U7.3 (EN)
unnamed: B1.SE, C1.1, L4.1
unnamed: C4.1, C12.1, L2.1, U1.35 (AVDD), U1.36 (AVDD)
unnamed: L1.2, U1.2 (DCC)
unnamed: L1.1, L2.2
unnamed: C2.1, U1.37 (XC1), X1.1
unnamed: C3.1, U1.38 (XC2), X1.3 (2)
unnamed: C5.1, U1.39 (DEC1)
unnamed: C8.1, U1.29 (DEC2)
unnamed: R16.2, R17.1, U7.4 (VFB)
unnamed: L3.2, U7.1 (SW)
unnamed: Q2.3 (D), Q3.2 (G), R20.1
unnamed: Q2.5 (G), R21.1, R24.2
unnamed: Q1.1 (D), Q2.2 (G), R13.1
unnamed: R11.1, U5.1 (O), U6.3 (V)
unnamed: Q1.3 (G), R14.2, R15.1, R23.2
unnamed: Q1.2 (S), R11.2
OV: R12.1, U1.7 (P03/AIN4), U6.1 (O)
RTC_CS: U1.4 (P00/AREF0); also elsewhere on the board
S1: SW1.1, U1.8 (P04/AIN5)
S2: SW1.4, U1.9 (P05/AIN6)
S3: SW1.2, U1.11 (P07)
S4: SW1.8, U1.14 (P08)
S5: SW2.1, U1.15 (P09)
S6: SW2.4, U1.16 (P10)
S7: SW2.2, U1.17 (P11)
S8: SW2.8, U1.18 (P12)
S9: SW3.1, U1.19 (P13)
S10: SW3.4, U1.20 (P14)
S11: SW3.2, U1.21 (P15)
S12: SW3.8, U1.22 (P16)
S13: SW4.1, U1.25 (P17)
S14: SW4.4, U1.26 (P18)
S15: SW4.2, U1.27 (P19)
S16: SW4.8, U1.28 (P20)
SCK: U1.44 (P25); also elsewhere on the board
SHDN: R24.1, U1.6 (P02/AIN3)
SWDCLK: R8.1, U1.24 (SWDCLK); also elsewhere on the board
SWDIO: U1.23 (SWDIO/!RESET); also elsewhere on the board
TRIG: R23.1, U1.5 (P01/AIN2)
VCAP: C15.1, C16.CATHODE, C17.CATHODE, C18.CATHODE, C19.CATHODE, C20.CATHODE, J2.1, JP1.1, L3.1, Q3.4 (S), R14.1, R19.1, U5.3 (V), U7.6 (VIN)
VDD_PA: B1.VCC (VDD_PA), C6.1, U1.30 (VDD_PA)
VREG: C9.1, C13.1, C14.1, JP1.2, R1.1, R16.1, U1.1 (VDD), U1.12 (VDD), U7.5 (VOUT); also elsewhere on the board

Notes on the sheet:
PIN12
PIN1
PIN36
VCAP
GND
SHD
TRIG
SOLAR
(Tantalum)
BUFFER
Voltage
MONITOR
OVERVOLT
DISCHARGE
EXTERNAL
TRIGGER
(Optional)
ENABLE
LATCH
BOOST VOLTAGE REGULATOR
INTERFACE

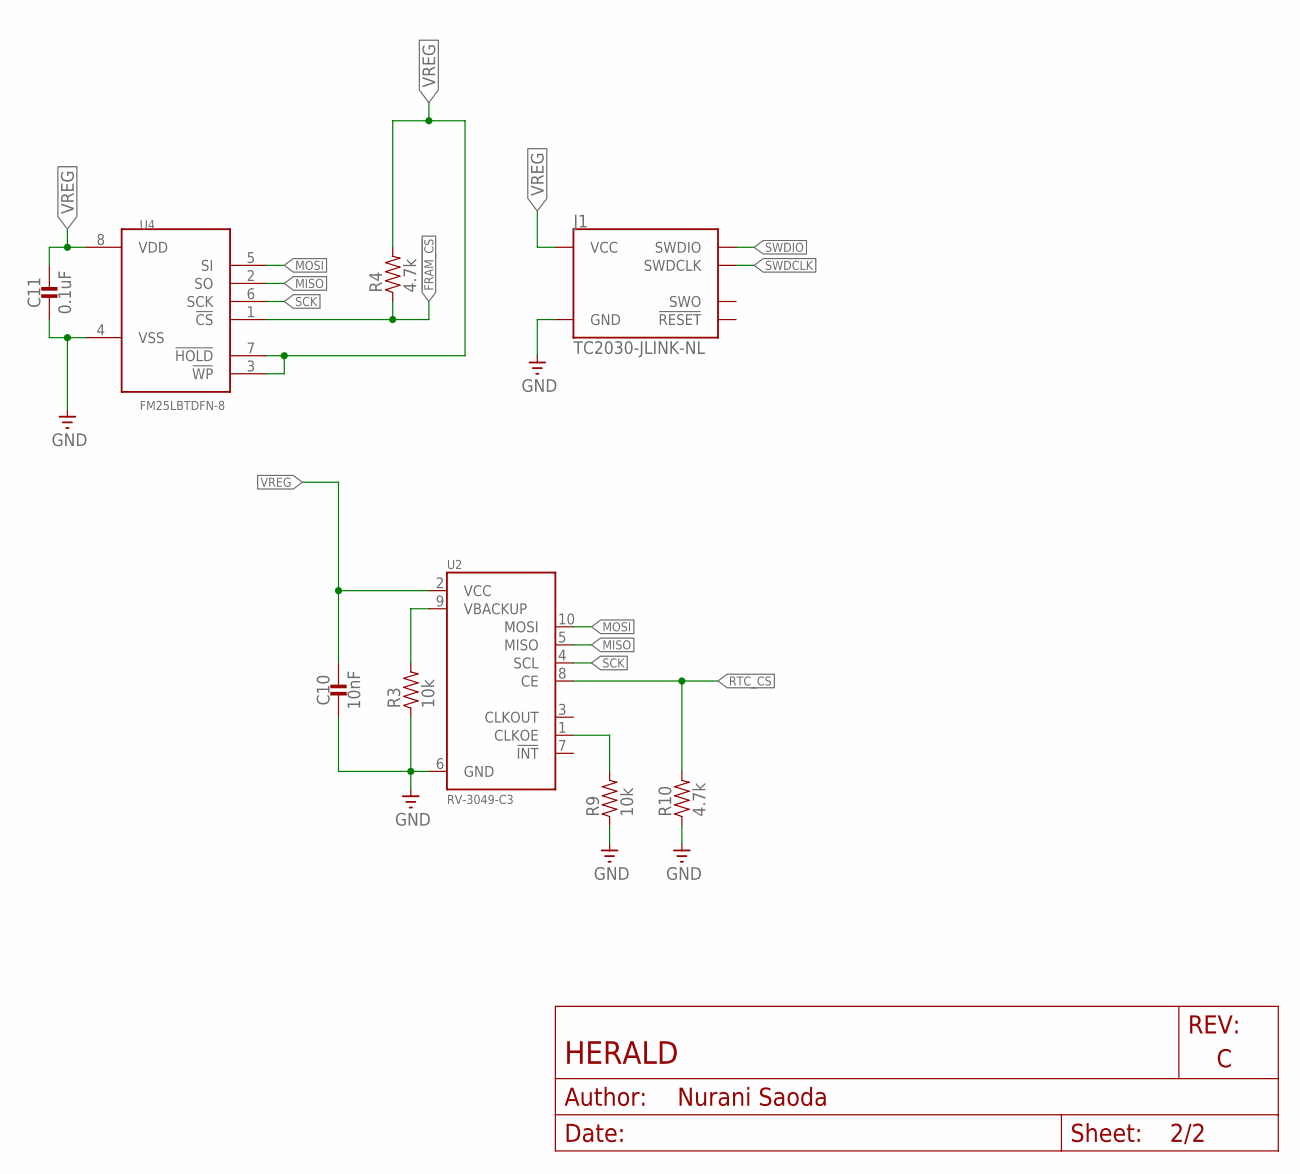
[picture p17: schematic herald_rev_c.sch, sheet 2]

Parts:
C10: 10nF; 0402_CAP
C11: 0.1uF; 0402_CAP
J1: TC2030-JLINK-NL; TC2030-IDC-NL
R3, R9: 10k; 0402_RES; DIGIKEY RHM10KCECT-ND
R4, R10: 4.7k; 0402_RES; DIGIKEY RHM4.7KCECT-ND
U2: RV-3049-C3; MICRO-CRYSTAL-C3
U4: FM25LBTDFN-8; TDFN-8@1; DIGIKEY FM25L04B-DGRA-ND

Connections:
!FRAM_CS: R4.1, U4.1 (!CS); also elsewhere on the board
GND: C10.2, C11.2, J1.5 (GND), R3.1, R9.1, R10.1, U2.6 (GND), U4.4 (VSS); also elsewhere on the board
MISO: U2.5 (MISO), U4.2 (SO); also elsewhere on the board
MOSI: U2.10 (MOSI), U4.5 (SI); also elsewhere on the board
unnamed: R3.2, U2.9 (VBACKUP)
unnamed: R9.2, U2.1 (CLKOE)
RTC_CS: R10.2, U2.8 (CE); also elsewhere on the board
SCK: U2.4 (SCL), U4.6 (SCK); also elsewhere on the board
SWDCLK: J1.4 (SWDCLK); also elsewhere on the board
SWDIO: J1.2 (SWDIO); also elsewhere on the board
VREG: C10.1, C11.1, J1.1 (VCC), R4.2, U2.2 (VCC), U4.3 (!WP), U4.7 (!HOLD), U4.8 (VDD); also elsewhere on the board

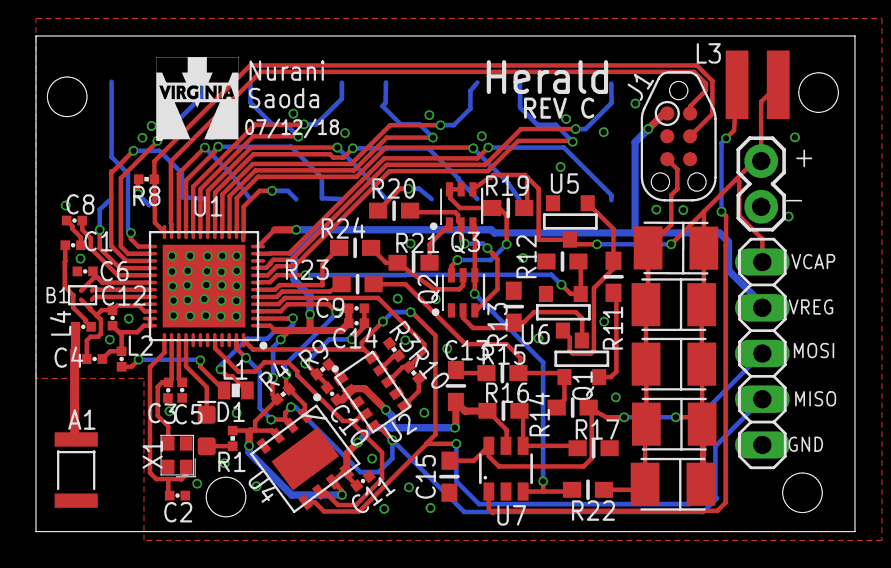
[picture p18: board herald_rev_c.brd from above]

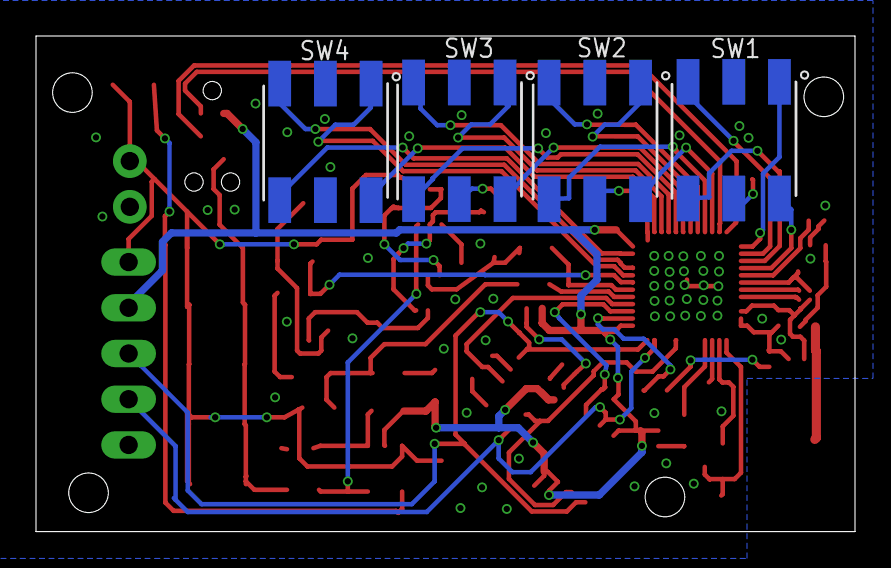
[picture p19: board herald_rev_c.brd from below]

Board: 2 copper layers, 45.5 x 27.5 mm, 62 parts (4 on the bottom side), 55 nets.

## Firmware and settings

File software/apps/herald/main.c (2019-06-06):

#include <stdint.h>
#include <stdio.h>
#include <string.h>
#include "nordic_common.h"
#include "nrf.h"
#include "nrf_sdm.h"
#include "nrf_delay.h"
#include "ble.h"
#include "ble_advdata.h"
#include "ble_db_discovery.h"
#include "softdevice_handler.h"
#include "ble_debug_assert_handler.h"
#include "app_util_platform.h"
#include "ble_conn_params.h"
#include "ble_hci.h"
//#include "boards.h"
#include "nrf_gpio.h"
#include "ble_hrs_c.h"
#include "ble_bas_c.h"
#include "ble_dis.h"
#include "app_timer.h"
#include "simple_ble.h"
#include "simple_adv.h"
#include "eddystone.h"

#include "nrf_drv_config.h"

//#include "fm25l04b.h"

#include "nrf_drv_spi.h"




#define BLE_ADVERTISING_ENABLED 1
#define DEVICE_NAME "herald"
#define PHYSWEB_URL "j2x.us/herald"

#define UVA_COMPANY_IDENTIFIER 0x02E0

#define UVA_MANDATA_SERVICE_HERALD 0x21
#define FM25L04B_nCS 30

#define MAGIC_ID 0x63F2BA02
#define FRAM_ADDR_MAGIC 4
#define FRAM_ADDR_COUNTER FRAM_ADDR_MAGIC + 4
#define FRAM_ADDR_SEQ_NO FRAM_ADDR_COUNTER + 4

#define EDDYSTONE_ADV_DURATION APP_TIMER_TICKS(500,APP_TIMER_PRESCALER)
#define MANUF_ADV_DURATION APP_TIMER_TICKS(500,APP_TIMER_PRESCALER)

APP_TIMER_DEF(start_eddystone_adv_timer);
APP_TIMER_DEF(start_manufdata_adv_timer);

void start_eddystone_adv(void);
void start_manufdata_adv(void);
void timers_init(void);
int main(void);

typedef struct {
    uint8_t service;
    uint8_t version;
    uint8_t room_no_4;
    uint8_t room_no_3;
    uint8_t room_no_2;
    uint8_t room_no_1;
    uint32_t counter;
    uint32_t seq_no;
    
} __attribute__((packed)) herald_mandata_t;

static herald_mandata_t herald_mandata = {
    UVA_MANDATA_SERVICE_HERALD,
    1, 
    0,
    0,
    0,
    0,
    0,
    0
};

static ble_advdata_manuf_data_t mandata = {
    UVA_COMPANY_IDENTIFIER,
    {

       14,
        (uint8_t*) &herald_mandata
    }
};


// static nrf_drive_spi_t _spi=NRF_DRV_SPI_INSTANCE(0);

// fm25l04b_t fm25l04b= {
// 	.spi = &_spi,
// 	.sck_pin = SPIO_CONFIG_SCK_PIN,
// 	.mosi_pin = SPIO_CONFIG_MOSI_PIN,
// 	.miso_pin= SPIO_CONFIG_MISO_PIN,
// 	.ss_pin = FM25L04B_nCS
// };


// typedef struct {
// 	uint32_t magic;
// 	uint32_t counter;
// 	uint32_t seq_no;
// }__attribute__((packed)) herald_fram_t;

// static herald_fram_t herald_fram;


// void gpio_init(){
// 	nrf_gpio_cfg_input(4, NRF_GPIO_PIN_PULLUP); //pins as input
// 	nrf_gpio_cfg_input(5, NRF_GPIO_PIN_PULLUP);
// 	nrf_gpio_range_cfg_input(7,20, NRF_GPIO_PIN_PULLUP);
// 	nrf_gpio_cfg_sense_input(4, NRF_GPIO_PIN_PULLUP,NRF_GPIO_PIN_SENSE_HIGH);
// 	nrf_gpio_cfg_sense_input(5, NRF_GPIO_PIN_PULLUP,NRF_GPIO_PIN_SENSE_HIGH);
// 	nrf_gpio_cfg_sense_input(7, NRF_GPIO_PIN_PULLUP,NRF_GPIO_PIN_SENSE_HIGH);
// 	nrf_gpio_cfg_sense_input(8, NRF_GPIO_PIN_PULLUP,NRF_GPIO_PIN_SENSE_HIGH);
// 	nrf_gpio_cfg_sense_input(10, NRF_GPIO_PIN_PULLUP,NRF_GPIO_PIN_SENSE_HIGH);
// 	nrf_gpio_cfg_sense_input(11, NRF_GPIO_PIN_PULLUP,NRF_GPIO_PIN_SENSE_HIGH);
// 	nrf_gpio_cfg_sense_input(12, NRF_GPIO_PIN_PULLUP,NRF_GPIO_PIN_SENSE_HIGH);
// 	nrf_gpio_cfg_sense_input(13, NRF_GPIO_PIN_PULLUP,NRF_GPIO_PIN_SENSE_HIGH);
// 	nrf_gpio_cfg_sense_input(14, NRF_GPIO_PIN_PULLUP,NRF_GPIO_PIN_SENSE_HIGH);
// 	nrf_gpio_cfg_sense_input(15, NRF_GPIO_PIN_PULLUP,NRF_GPIO_PIN_SENSE_HIGH);
// 	nrf_gpio_cfg_sense_input(16, NRF_GPIO_PIN_PULLUP,NRF_GPIO_PIN_SENSE_HIGH);
// 	nrf_gpio_cfg_sense_input(17, NRF_GPIO_PIN_PULLUP,NRF_GPIO_PIN_SENSE_HIGH);
// 	nrf_gpio_cfg_sense_input(18, NRF_GPIO_PIN_PULLUP,NRF_GPIO_PIN_SENSE_HIGH);
// 	nrf_gpio_cfg_sense_input(19, NRF_GPIO_PIN_PULLUP,NRF_GPIO_PIN_SENSE_HIGH);
// 	nrf_gpio_cfg_sense_input(20, NRF_GPIO_PIN_PULLUP,NRF_GPIO_PIN_SENSE_HIGH);
// 	nrf_gpio_cfg_sense_input(9, NRF_GPIO_PIN_PULLUP,NRF_GPIO_PIN_SENSE_HIGH);
// }


// uint32_t gpio_get_Sw1Data(){

// 	uint32_t SW1_1=(nrf_gpio_pin_read(SW1_PIN1))^1;
// 	uint32_t SW1_2=(nrf_gpio_pin_read(SW1_PIN2))^1;
// 	uint32_t SW1_4=(nrf_gpio_pin_read(SW1_PIN4))^1;
// 	uint32_t SW1_8=(nrf_gpio_pin_read(SW1_PIN8))^1;
// 	uint32_t SW1_bin = SW1_8 << 3 | SW1_4 << 2 |SW1_2 << 1 | SW1_1;
// 	return SW1_bin;
// }

// uint32_t gpio_get_Sw2Data(){
	
// 	uint32_t SW2_1=(nrf_gpio_pin_read(SW2_PIN1))^1;
// 	uint32_t SW2_2=(nrf_gpio_pin_read(SW2_PIN2))^1;
// 	uint32_t SW2_4=(nrf_gpio_pin_read(SW2_PIN4))^1;
// 	uint32_t SW2_8=(nrf_gpio_pin_read(SW2_PIN8))^1;
// 	uint32_t SW2_bin = SW2_8 << 3 | SW2_4 << 2 |SW2_2 << 1 | SW2_1;
// 	return SW2_bin;
// }

// uint32_t gpio_get_Sw3Data(){
	
// 	uint32_t SW3_1=(nrf_gpio_pin_read(SW3_PIN1))^1;
// 	uint32_t SW3_2=(nrf_gpio_pin_read(SW3_PIN2))^1;
// 	uint32_t SW3_4=(nrf_gpio_pin_read(SW3_PIN4))^1;
// 	uint32_t SW3_8=(nrf_gpio_pin_read(SW3_PIN8))^1;
	
// 	uint32_t SW3_bin = SW3_8 << 3 | SW3_4 << 2 |SW3_2 << 1 | SW3_1;
// 	return SW3_bin;

// }
	

// uint32_t gpio_get_Sw4Data(){	
// 	uint32_t SW4_1=(nrf_gpio_pin_read(SW4_PIN1))^1;
// 	uint32_t SW4_2=(nrf_gpio_pin_read(SW4_PIN2))^1;
// 	uint32_t SW4_4=(nrf_gpio_pin_read(SW4_PIN4))^1;
// 	uint32_t SW4_8=(nrf_gpio_pin_read(SW4_PIN8))^1;
// 	uint32_t SW4_bin = SW4_8 << 3 | SW4_4 << 2 |SW4_2 << 1 | SW4_1;
// 	return SW4_bin;
	
// }
	
static simple_ble_config_t ble_config = {
	.platform_id = 0x00,              // used as 4th octect in device BLE address
	.device_id = DEVICE_ID_DEFAULT,
	.adv_name = DEVICE_NAME,       // used in advertisements if there is room
	.adv_interval = MSEC_TO_UNITS(500, UNIT_0_625_MS),
	.min_conn_interval = MSEC_TO_UNITS(50, UNIT_1_25_MS),
	.max_conn_interval = MSEC_TO_UNITS(100, UNIT_1_25_MS),
};

void timers_init(void){
	uint32_t err_code;

	err_code=app_timer_create(&start_eddystone_adv_timer, APP_TIMER_MODE_SINGLE_SHOT, (app_timer_timeout_handler_t)start_eddystone_adv);
	APP_ERROR_CHECK(err_code);

	err_code=app_timer_create(&start_manufdata_adv_timer, APP_TIMER_MODE_SINGLE_SHOT, (app_timer_timeout_handler_t)start_manufdata_adv);
	APP_ERROR_CHECK(err_code);
}

void start_eddystone_adv(void){
	uint32_t err_code;
	eddystone_with_manuf_adv(PHYSWEB_URL, &mandata);

	err_code=app_timer_start(start_eddystone_adv_timer,EDDYSTONE_ADV_DURATION, NULL);

	APP_ERROR_CHECK(err_code);
}

void start_manufdata_adv(void){
	uint32_t err_code;

	uint32_t sw1= 3 ;
	
	uint32_t sw2= 2;
	
	uint32_t sw3= 1;
	
	uint32_t sw4= 0;
	

    herald_mandata.room_no_1=sw1+0x30;
	herald_mandata.room_no_2=sw2+0x30;
	herald_mandata.room_no_3=sw3+0x30;
	herald_mandata.room_no_4=sw4+0x30;
	herald_mandata.counter++;
    herald_mandata.seq_no++;

    simple_adv_manuf_data(&mandata);

    err_code=app_timer_start(start_manufdata_adv_timer, MANUF_ADV_DURATION, NULL);

	APP_ERROR_CHECK(err_code);



}




int main(void) {
        
	//gpio_init();
	// uint32_t sw1= 3 ;
	
	// uint32_t sw2= 2;
	
	// uint32_t sw3= 1;
	
	// uint32_t sw4= 0;
	

 //    herald_mandata.room_no_1=sw1+0x30;
	// herald_mandata.room_no_2=sw2+0x30;
	// herald_mandata.room_no_3=sw3+0x30;
	// herald_mandata.room_no_4=sw4+0x30;
	simple_ble_init(&ble_config);
	timers_init();
	start_manufdata_adv();
	//start_eddystone_adv();
    //simple_adv_only_name();
	
	
// 	if (herald_fram.magic != MAGIC_ID) {
// 		herald_fram.magic= MAGIC_ID;
// 		fm25l04b_write(&fm25l04b, FRAM_ADDR_MAGIC, (uint8_t*) &herald_fram, 4);
// 		herald_fram.counter =0;
// 		herald_fram.seq_no = 0;
		
// } 
// 	fm25l04b_read(&fm25l04b, FRAM_ADDR_MAGIC, (uint8_t*) &herald_fram, sizeof		(herald_fram_t));
// 	herald_fram.counter++;
// 	herald_fram.seq_no++;
// 	fm25l04b_write(&fm25l04b, FRAM_ADDR_COUNTER, ((uint8_t*) &herald_fram)+4, 8);
 //    herald_mandata.counter++;
 //    herald_mandata.seq_no++;

	// herald_mandata.counter=herald_mandata.counter;
	// herald_mandata.seq_no= herald_mandata.seq_no;


	// simple_adv_manuf_data(&mandata);
	
	// eddystone_with_manuf_adv (PHYSWEB_URL, &mandata);

	


	// Enter main loop
	while (1) {
		power_manage();
		
		
	}
}

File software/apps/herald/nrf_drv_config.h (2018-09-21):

/* Copyright (c) 2015 Nordic Semiconductor. All Rights Reserved.
 *
 * The information contained herein is property of Nordic Semiconductor ASA.
 * Terms and conditions of usage are described in detail in NORDIC
 * SEMICONDUCTOR STANDARD SOFTWARE LICENSE AGREEMENT.
 *
 * Licensees are granted free, non-transferable use of the information. NO
 * WARRANTY of ANY KIND is provided. This heading must NOT be removed from
 * the file.
 *
 */

#ifndef NRF_DRV_CONFIG_H
#define NRF_DRV_CONFIG_H

/**
 * Provide a non-zero value here in applications that need to use several
 * peripherals with the same ID that are sharing certain resources
 * (for example, SPI0 and TWI0). Obviously, such peripherals cannot be used
 * simultaneously. Therefore, this definition allows to initialize the driver
 * for another peripheral from a given group only after the previously used one
 * is uninitialized. Normally, this is not possible, because interrupt handlers
 * are implemented in individual drivers.
 * This functionality requires a more complicated interrupt handling and driver
 * initialization, hence it is not always desirable to use it.
 */
#define PERIPHERAL_RESOURCE_SHARING_ENABLED  0

/* CLOCK */
#define CLOCK_ENABLED 0

#if (CLOCK_ENABLED == 1)
#define CLOCK_CONFIG_XTAL_FREQ          NRF_CLOCK_XTALFREQ_Default
#define CLOCK_CONFIG_LF_SRC             NRF_CLOCK_LF_SRC_Xtal
#define CLOCK_CONFIG_IRQ_PRIORITY       APP_IRQ_PRIORITY_LOW
#endif

/* GPIOTE */
#define GPIOTE_ENABLED 0

#if (GPIOTE_ENABLED == 1)
#define GPIOTE_CONFIG_USE_SWI_EGU false
#define GPIOTE_CONFIG_IRQ_PRIORITY APP_IRQ_PRIORITY_LOW
#define GPIOTE_CONFIG_NUM_OF_LOW_POWER_EVENTS 1
#endif

/* TIMER */
#define TIMER0_ENABLED 0

#if (TIMER0_ENABLED == 1)
#define TIMER0_CONFIG_FREQUENCY    NRF_TIMER_FREQ_16MHz
#define TIMER0_CONFIG_MODE         TIMER_MODE_MODE_Timer
#define TIMER0_CONFIG_BIT_WIDTH    TIMER_BITMODE_BITMODE_32Bit
#define TIMER0_CONFIG_IRQ_PRIORITY APP_IRQ_PRIORITY_LOW

#define TIMER0_INSTANCE_INDEX      0
#endif

#define TIMER1_ENABLED 0

#if (TIMER1_ENABLED == 1)
#define TIMER1_CONFIG_FREQUENCY    NRF_TIMER_FREQ_16MHz
#define TIMER1_CONFIG_MODE         TIMER_MODE_MODE_Timer
#define TIMER1_CONFIG_BIT_WIDTH    TIMER_BITMODE_BITMODE_16Bit
#define TIMER1_CONFIG_IRQ_PRIORITY APP_IRQ_PRIORITY_LOW

#define TIMER1_INSTANCE_INDEX      (TIMER0_ENABLED)
#endif

#define TIMER2_ENABLED 0

#if (TIMER2_ENABLED == 1)
#define TIMER2_CONFIG_FREQUENCY    NRF_TIMER_FREQ_16MHz
#define TIMER2_CONFIG_MODE         TIMER_MODE_MODE_Timer
#define TIMER2_CONFIG_BIT_WIDTH    TIMER_BITMODE_BITMODE_16Bit
#define TIMER2_CONFIG_IRQ_PRIORITY APP_IRQ_PRIORITY_LOW

#define TIMER2_INSTANCE_INDEX      (TIMER1_ENABLED+TIMER0_ENABLED)
#endif

#define TIMER3_ENABLED 0

#if (TIMER3_ENABLED == 1)
#define TIMER3_CONFIG_FREQUENCY    NRF_TIMER_FREQ_16MHz
#define TIMER3_CONFIG_MODE         TIMER_MODE_MODE_Timer
#define TIMER3_CONFIG_BIT_WIDTH    TIMER_BITMODE_BITMODE_16Bit
#define TIMER3_CONFIG_IRQ_PRIORITY APP_IRQ_PRIORITY_LOW

#define TIMER3_INSTANCE_INDEX      (TIMER2_ENABLED+TIMER1_ENABLED+TIMER0_ENABLED)
#endif

#define TIMER4_ENABLED 0

#if (TIMER4_ENABLED == 1)
#define TIMER4_CONFIG_FREQUENCY    NRF_TIMER_FREQ_16MHz
#define TIMER4_CONFIG_MODE         TIMER_MODE_MODE_Timer
#define TIMER4_CONFIG_BIT_WIDTH    TIMER_BITMODE_BITMODE_16Bit
#define TIMER4_CONFIG_IRQ_PRIORITY APP_IRQ_PRIORITY_LOW

#define TIMER4_INSTANCE_INDEX      (TIMER3_ENABLED+TIMER2_ENABLED+TIMER1_ENABLED+TIMER0_ENABLED)
#endif


#define TIMER_COUNT (TIMER0_ENABLED + TIMER1_ENABLED + TIMER2_ENABLED + TIMER3_ENABLED + TIMER4_ENABLED)

/* RTC */
#define RTC0_ENABLED 0

#if (RTC0_ENABLED == 1)
#define RTC0_CONFIG_FREQUENCY    32678
#define RTC0_CONFIG_IRQ_PRIORITY APP_IRQ_PRIORITY_LOW
#define RTC0_CONFIG_RELIABLE     false

#define RTC0_INSTANCE_INDEX      0
#endif

#define RTC1_ENABLED 0

#if (RTC1_ENABLED == 1)
#define RTC1_CONFIG_FREQUENCY    32768
#define RTC1_CONFIG_IRQ_PRIORITY APP_IRQ_PRIORITY_LOW
#define RTC1_CONFIG_RELIABLE     false

#define RTC1_INSTANCE_INDEX      (RTC0_ENABLED)
#endif

#define RTC_COUNT                (RTC0_ENABLED+RTC1_ENABLED)

#define NRF_MAXIMUM_LATENCY_US 2000

/* RNG */
#define RNG_ENABLED 0

#if (RNG_ENABLED == 1)
#define RNG_CONFIG_ERROR_CORRECTION true
#define RNG_CONFIG_POOL_SIZE        8
#define RNG_CONFIG_IRQ_PRIORITY     APP_IRQ_PRIORITY_LOW
#endif

/* PWM */

#define PWM0_ENABLED 0

#if (PWM0_ENABLED == 1)
#define PWM0_CONFIG_OUT0_PIN        2
#define PWM0_CONFIG_OUT1_PIN        3
#define PWM0_CONFIG_OUT2_PIN        4
#define PWM0_CONFIG_OUT3_PIN        5
#define PWM0_CONFIG_IRQ_PRIORITY    APP_IRQ_PRIORITY_LOW
#define PWM0_CONFIG_BASE_CLOCK      NRF_PWM_CLK_1MHz
#define PWM0_CONFIG_COUNT_MODE      NRF_PWM_MODE_UP
#define PWM0_CONFIG_TOP_VALUE       1000
#define PWM0_CONFIG_LOAD_MODE       NRF_PWM_LOAD_COMMON
#define PWM0_CONFIG_STEP_MODE       NRF_PWM_STEP_AUTO

#define PWM0_INSTANCE_INDEX 0
#endif

#define PWM1_ENABLED 0
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

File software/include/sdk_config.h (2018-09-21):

#ifndef SDK_CONFIG_H
#define SDK_CONFIG_H
// <<< Use Configuration Wizard in Context Menu >>>\n
#ifdef USE_APP_CONFIG
#include "app_config.h"
#endif
// <h> nRF_BLE

//==========================================================
// <q> BLE_ADVERTISING_ENABLED  - ble_advertising - Advertising module


#ifndef BLE_ADVERTISING_ENABLED
#define BLE_ADVERTISING_ENABLED 1
#endif

// <q> BLE_DTM_ENABLED  - ble_dtm - Module for testing RF/PHY using DTM commands


#ifndef BLE_DTM_ENABLED
#define BLE_DTM_ENABLED 0
#endif

// <q> BLE_RACP_ENABLED  - ble_racp - Record Access Control Point library


#ifndef BLE_RACP_ENABLED
#define BLE_RACP_ENABLED 0
#endif

// <q> NRF_BLE_QWR_ENABLED  - nrf_ble_qwr - Queued writes support module (prepare/execute write)


#ifndef NRF_BLE_QWR_ENABLED
#define NRF_BLE_QWR_ENABLED 0
#endif

// <q> PEER_MANAGER_ENABLED  - peer_manager - Peer Manager


#ifndef PEER_MANAGER_ENABLED
#define PEER_MANAGER_ENABLED 0
#endif

// </h>
//==========================================================

// <h> nRF_BLE_Services

//==========================================================
// <q> BLE_ANCS_C_ENABLED  - ble_ancs_c - Apple Notification Service Client


#ifndef BLE_ANCS_C_ENABLED
#define BLE_ANCS_C_ENABLED 0
#endif

// <q> BLE_ANS_C_ENABLED  - ble_ans_c - Alert Notification Service Client


#ifndef BLE_ANS_C_ENABLED
#define BLE_ANS_C_ENABLED 0
#endif

// <q> BLE_BAS_C_ENABLED  - ble_bas_c - Battery Service Client


#ifndef BLE_BAS_C_ENABLED
#define BLE_BAS_C_ENABLED 0
#endif

// <q> BLE_BAS_ENABLED  - ble_bas - Battery Service


#ifndef BLE_BAS_ENABLED
#define BLE_BAS_ENABLED 0
#endif

// <q> BLE_CSCS_ENABLED  - ble_cscs - Cycling Speed and Cadence Service


#ifndef BLE_CSCS_ENABLED
#define BLE_CSCS_ENABLED 0
#endif

// <q> BLE_CTS_C_ENABLED  - ble_cts_c - Current Time Service Client


#ifndef BLE_CTS_C_ENABLED
#define BLE_CTS_C_ENABLED 0
#endif

// <q> BLE_DIS_ENABLED  - ble_dis - Device Information Service


#ifndef BLE_DIS_ENABLED
#define BLE_DIS_ENABLED 0
#endif

// <q> BLE_GLS_ENABLED  - ble_gls - Glucose Service


#ifndef BLE_GLS_ENABLED
#define BLE_GLS_ENABLED 0
#endif

// <q> BLE_HIDS_ENABLED  - ble_hids - Human Interface Device Service


#ifndef BLE_HIDS_ENABLED
#define BLE_HIDS_ENABLED 0
#endif

// <e> BLE_HRS_C_ENABLED - ble_hrs_c - Heart Rate Service Client
//==========================================================
#ifndef BLE_HRS_C_ENABLED
#define BLE_HRS_C_ENABLED 0
#endif
#if  BLE_HRS_C_ENABLED
// <o> BLE_HRS_C_RR_INTERVALS_MAX_CNT - Maximum number of RR_INTERVALS per notification to be decoded
#ifndef BLE_HRS_C_RR_INTERVALS_MAX_CNT
#define BLE_HRS_C_RR_INTERVALS_MAX_CNT 30
#endif

#endif //BLE_HRS_C_ENABLED
// </e>

// <q> BLE_HRS_ENABLED  - ble_hrs - Heart Rate Service


#ifndef BLE_HRS_ENABLED
#define BLE_HRS_ENABLED 0
#endif

// <q> BLE_HTS_ENABLED  - ble_hts - Health Thermometer Service


#ifndef BLE_HTS_ENABLED
#define BLE_HTS_ENABLED 0
#endif

// <q> BLE_IAS_C_ENABLED  - ble_ias_c - Immediate Alert Service Client


#ifndef BLE_IAS_C_ENABLED
#define BLE_IAS_C_ENABLED 0
#endif

// <q> BLE_IAS_ENABLED  - ble_ias - Immediate Alert Service


#ifndef BLE_IAS_ENABLED
#define BLE_IAS_ENABLED 0
#endif

// <q> BLE_LBS_C_ENABLED  - ble_lbs_c - Nordic LED Button Service Client


#ifndef BLE_LBS_C_ENABLED
#define BLE_LBS_C_ENABLED 0
#endif

// <q> BLE_LBS_ENABLED  - ble_lbs - LED Button Service


#ifndef BLE_LBS_ENABLED
#define BLE_LBS_ENABLED 0
#endif

// <q> BLE_LLS_ENABLED  - ble_lls - Link Loss Service


#ifndef BLE_LLS_ENABLED
#define BLE_LLS_ENABLED 0
#endif

// <q> BLE_NUS_C_ENABLED  - ble_nus_c - Nordic UART Central Service


#ifndef BLE_NUS_C_ENABLED
#define BLE_NUS_C_ENABLED 0
#endif

// <q> BLE_NUS_ENABLED  - ble_nus - Nordic UART Service


#ifndef BLE_NUS_ENABLED
#define BLE_NUS_ENABLED 0
#endif

// <q> BLE_RSCS_C_ENABLED  - ble_rscs_c - Running Speed and Cadence Client


#ifndef BLE_RSCS_C_ENABLED
#define BLE_RSCS_C_ENABLED 0
#endif

// <q> BLE_RSCS_ENABLED  - ble_rscs - Running Speed and Cadence Service


#ifndef BLE_RSCS_ENABLED
#define BLE_RSCS_ENABLED 0
#endif

// <q> BLE_TPS_ENABLED  - ble_tps - TX Power Service


#ifndef BLE_TPS_ENABLED
#define BLE_TPS_ENABLED 0
#endif

// </h>
//==========================================================

// <h> nRF_Drivers

//==========================================================
// <e> ADC_ENABLED - nrf_drv_adc - Driver for ADC peripheral (nRF51)
//==========================================================
#ifndef ADC_ENABLED
#define ADC_ENABLED 0
#endif
#if  ADC_ENABLED
// <o> ADC_CONFIG_IRQ_PRIORITY  - Interrupt priority


// <i> Priorities 0,2 (nRF51) and 0,1,4,5 (nRF52) are reserved for SoftDevice
// <0=> 0 (highest)
// <1=> 1
// <2=> 2
// <3=> 3

#ifndef ADC_CONFIG_IRQ_PRIORITY
#define ADC_CONFIG_IRQ_PRIORITY 3
#endif
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

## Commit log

2018-09-21 drivers updated:Wq
2019-08-06 Added herald prototype picture and case

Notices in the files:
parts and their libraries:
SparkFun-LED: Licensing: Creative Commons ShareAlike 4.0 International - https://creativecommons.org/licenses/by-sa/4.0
